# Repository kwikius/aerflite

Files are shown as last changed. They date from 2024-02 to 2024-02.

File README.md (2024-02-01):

A Fork of Ardupilot for a barebones STM32 running FreeRTOS and an onChip OSD
----------------------------------------------------------------------------

BuildInfo
---------

Building apm_quantracker

$$> export QUAN_TARGET_VEHICLE=QUAN_APM_ARDUPLANE

$$> export QUANTRACKER_ROOT_DIR=\<path to quantracker\>

$$> cd ardupilot/ArduPlane

$$> make quan

Dependencies
------------

The dependencies can be retrieved on linux by downloading building and running the installer
air_installer from github.  https://github.com/kwikius/air_installer

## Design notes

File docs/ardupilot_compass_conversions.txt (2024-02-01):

represnt z,y,z 1 means axis not flipped -1 means sign of axis flipped

output orientation  when chip is mounted on upper face of pcb and x is facing west

abbreviations W == wste,  E == east, S == south, N == north U = Up D = down
from datasheets where the chip text is written to be read normally x axis horizontal is pointing out to the right
e.g WNU is x points west , y points north, z points up
RHR is right hand rule

AK8963   [1,1,1]     ENU  or WSD  dependendt on part ( both RHR)        
AK09916  [1,1,1]     ENU
BMM150   [1,1,1]
HMC5843  [-1,1,-1]
IST8308  [1,1,-1]
IST8310  [1,1,-1]
LIS3MDL  [1,1,1]
LSM9DS1  [1,1,1]
LSM303   [1,1,1]
MAG3110  [1,1,1]
MMX5xx3  [1,1,1]
MMC3146  [1,1,1]
MSP      [1,1,1]
PX4      [1,1,1]
QMC5883  [-1,1,-1]
QURT     [1,1,-1]
RM3100    hardware modifiable?
Qflight [1,1,-1]

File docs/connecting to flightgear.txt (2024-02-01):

in (ardupilot) AP_HAL_SITL/SITL_State.cpp 99 connect to socket out from ardupilot to flightgear

in (ardupilot) AP_HAL_SITL/SITL_State.cpp 302 output to flightgear function

called from SITL_STATE::fdm_input_step through _fdm_input_local();

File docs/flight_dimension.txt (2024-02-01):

dimensions relating to flight
dimensions are within universe of a frame for example body_frame world_frame

angular_frame
 The pose within some linear_frame
   can be euler or quaternion 
   euler {pitch yaw roll}
   quaternion { w, x, y, z }

   pose : quaternion  
   angular_velocity : 3d vector angle/time
   angular_acceleration  3d vector angle / (time^2)
   Torque : 3d vector force * distance

linear_frame 
   position
   velocity
   acceleration
   jerk

aircraft related
   Thrust : linear_frame
   Drag : linear frame

FlightGear FlightDimension
   
   Thrust

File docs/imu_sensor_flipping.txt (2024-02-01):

IMU sensor flipping

The imu necessarily requires the sensor data to be in correct orientation

for aerflite the accel and gyro flipping is in the imu interrupt handler
in AP_HAL_QUAN/imu_task_aerflite.cpp
The compass flipping is in the Quan::compass_calculat function in AP_HAL_QUAN/lis3_mdl.cpp

AP inertial sensor parameters ............
Product id
Gyro Offsets
Accelerometer scaling
Accelerometer offsets
Gyro Filter
Accelerometer Filter
Use accelerometer
Still threshold
Gyro calibration scheme

AHRS parameters

GPS gain

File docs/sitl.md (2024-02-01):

Software in the loop
--------------------

SITL components
   - Physics
      - engine
      - actor specification
      - environment specification

  - Visualisation
      - engine
      - actor specification
      - environment specification

   - Sensors
      - Actor Pose
         - Linear position
         - Linear velocity
         - Linear acceleration
         - Angular position
         - Angular velocity
       - environment
         - wind

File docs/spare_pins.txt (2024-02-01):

Aerflite possible spare pins

PA4  currently used for video DAC out

PA12 CAN_TX
PA11 CAN_RX

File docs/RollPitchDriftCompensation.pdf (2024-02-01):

Roll-pitch compensation | - 1 - | December 1, 2011

Roll-Pitch Gyro Drift Compensation

William Premerlani, December 1, 2011

Problem
We wish to use an accelerometer and GPS to detect gyro roll-pitch drift in an IMU, without any information about orientation of the aircraft with respect to air speed vector.

Background
During the development of the theoretical foundations of MatrixPilot, the conventional wisdom of the DIY UAV community was that the best way to account for acceleration in roll-pitch drift compensation is to compute the acceleration in the body frame, using GPS acceleration to determine forward acceleration, and the cross product of the aircraft velocity vector with gyro rotation to compute cross acceleration. In order for this technique to be accurate, the angles of attack and side slip must be known, estimated, or assumed. In the case of fixed wing aircraft, this introduces errors during high acceleration. In the case multicopters, this introduces very large errors, because a multicopter does not naturally align itself with the direction of flight. So, a method that does not require attack and side slip angles would be more accurate.

Solution
The solution is trivial if you use gravity minus acceleration as the reference vector, rather than gravity. In the body (aircraft) frame of reference, the vectors reported by the accelerometer are the differences between the gravity and acceleration vectors, as seen in the body frame of reference:
( ) ( ) ( )
( )
( )
( ) output of accelerometer acceleration, asseen in body frame gravity, asseen in body frame

=

=

=

= -

t

t

t

t | t | t

b

b

b

b | b | b

A

a

g

A | g | a

Equation 1

Our estimate of the rotation matrix provides a connection between body and earth frame of reference:
( ) ( ) ( )

( )
( ) our estimate of the rotation matrix acceleration, asseen in earth frame gravity, asseen in earth frame

=

=

=

- = -

t

t

t | t | t

R

a

g

R | A | g a

e

e

b | e | e
Equation 2

If our estimate of the rotation matrix were correct, equation 2 would be an identity. However, because of gyro drift, equation 2 will not be exactly satisfied. In particular, the

Roll-pitch compensation | - 2 - | December 1, 2011

cross product of the vectors on the left and right hand side of Equation 2 is an indication of the drift error. To improve accuracy, it is a good idea to integrate both sides of the equation between GPS reports. That way we can use velocity information instead of acceleration:
( ) ( ) | ( 2 1) | ( ( 2) ( 1))

2

1

d | t | t | t | t

t

t

R | Ab | ge - Ve | - Ve · | · = | - · Ú t | t t | Equation 3

Use equation 3 on a regular basis (such as synchronized with GPS messages) to estimate drift. The left side is computed as the sum of multiplications of the rotation matrix with the accelerometer output. The first term on the right hand side is the time interval times the known, constant gravity vector. The second term is the difference in velocity vectors reported by the GPS.
Take the cross product of the left hand side of equation 3 with the right hand side. This is an indication of the drift rotation. Note that this method is capable of detecting yaw drift as well as roll-pitch, if the aircraft is accelerating laterally. So, it can be integrated with magnetometer yaw drift compensation. Also note that no assumptions have been made about the orientation of the aircraft.
So, the error rotation vector is given by:
( ) | ( ) ( ) | (( 2 1) | ( ( 2) ( 1))) 2

2

1

t | d | t | t | t | t

t

t

earth | b | e | Ve | Ve error | R | A | ¥ | - ·g - | - ˜

˜
¯

ˆ
Á

Á
Ë
Ê = | · | · Ú t | t t

Equation 4
Finally, transform the error in the body frame of reference. It can then be used directly as an input to the drift PI feedback controller:
( 2) | ( 2) t | t body | earth error | R | error T = | · | Equation 5

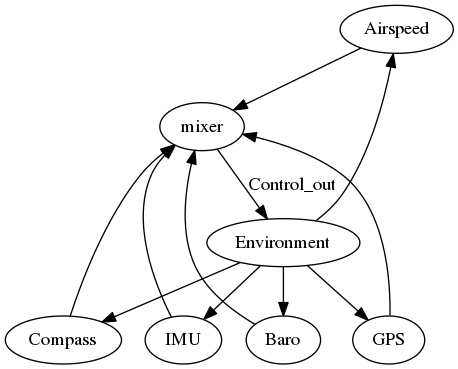
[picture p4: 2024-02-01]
docs/SITL/fc_as_mixer.png

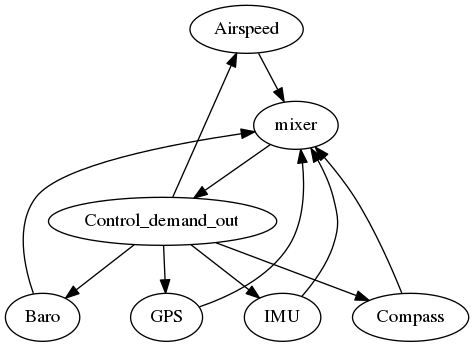
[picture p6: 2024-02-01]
docs/fc_mixer.png

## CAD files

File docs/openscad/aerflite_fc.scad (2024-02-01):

use <axes.scad>

module arrow_axes(){
   RHR_axes(){arrow();arrow(); arrow();}
}
module BMI160_arrow_n_rotation_axes(){
   RHR_axes(){
   arrow_n_rotation_arrow_rhs(); 
   arrow_n_rotation_arrow_rhs();
   arrow_n_rotation_arrow_rhs();
}
}

module board_arrow_n_rotation_axes(){
   rotate([180,0,0]){
   RHR_axes(){
   arrow_n_rotation_arrow_rhs(); 
   arrow_n_rotation_arrow_rhs();
   arrow_n_rotation_arrow_rhs();
}
}
}

translate([70,0,5]){
   translate([3,3,0]){
      text("board_orient",size = 2);
   }
   rotate([0,0,0]){
      board_arrow_n_rotation_axes();
   }
}


translate([0,50,5]){
   translate([3,3,0]){
      text("compass_orient",size = 2);
   }
   rotate([0,0,270]){
     arrow_axes();
   }
}


translate([-70,0,5]){
   translate([3,3,0]){
      text("BMI160_orient",size = 2);
   }
   rotate([0,0,90]){
      BMI160_arrow_n_rotation_axes();
   }
}

text_size = 2;
show_raspberry_pi = false;
module JST_SH1_horz(n_pins,name_text)
{
  translate([-4,-(n_pins + 2)/2,0]){
  	  cube ([4,n_pins + 2,3]);
  }
  translate([-2,-(n_pins + 3)/2,0]){
	  cube ([2,n_pins + 3,0.5]);
  }
  for ( i= [-(n_pins-1)/2:1: (n_pins-1)/2]){
	 translate([-5.5, i -0.25,0]){
		cube([1.5,0.5,0.25]);
	 }
  }
  translate([1,0,1]){
      text(name_text,size = text_size);
  }
}

module raspberry_pi_zero()
{
     difference(){
	 cube([65,30,5], center = true);
      translate([27,-1,-0]){
        rotate([0,180,0]){
        linear_extrude(height = 3) {
           text("Raspberry Pi Zero", size =  5);
        }
     }
      }
  }
}

module JST_GH_horz( n_pins,name_text)
{
  for ( i= [-(n_pins-1)/2:1: (n_pins-1)/2]){
	 translate([-5.4, i *1.25 -0.3,0]){
		cube([1.4,0.6,0.1]);
	 }
  }
  for ( i = [-1:2:1]){
		translate([-2.7,((n_pins-1)/2*1.25 +1.85)*i -0.5,0]){
			cube([2.7,1,0.1]);
		}
  }
  width = (n_pins-1) + 4.5;
  thickness = 0.5;
  difference(){
  translate([-4.05,-width/2,0]){
	cube([4.05,width,4.25]);
  }

  translate([-4.05 + thickness,-(width/2)+thickness,thickness]){
	cube([5,width - 2*thickness,4.25 - 2*thickness]);
  }
  }
   translate([1,0,1]){
      text(name_text,size = text_size);
  }
  
}

module JST_GH_vert( n_pins,name_text)
{
  for ( i= [-(n_pins-1)/2:1: (n_pins-1)/2]){
	 translate([-5.6, i *1.25 -0.3,0]){
		cube([1.7,0.6,0.1]);
	 }
  }
  for ( i = [-1:2:1]){
		translate([-2.8,((n_pins-1)/2*1.25 +1.85)*i -0.5,0]){
			cube([2.8,1,0.1]);
		}
  }
  width = (n_pins-1) + 4.5;
  thickness = 0.5;
  difference(){
  translate([-4.25,-width/2,0]){
	cube([4.25,width,4.05]);
  }

  translate([-4.25 + thickness,-(width/2)+thickness,thickness]){
	cube([4.25 - 2 * thickness,width - 2*thickness,5]);
  }
  }
  translate([1,0,1]){
      text(name_text,size = text_size);
  }
  
}


module hdr_pin()
{
	translate([-3,-0.32, -0.32]){
		cube([11.5,0.64,0.64]);
	}
   translate([0,-1.27,-1.27]){
		cube([2.54,2.54,2.54]);
	}
}
module rc_in_hdr()
{
	for (col = [-2.5:1:2.5]){
		for (row = [-1:1:1]){
         translate([0,col * 2.54,row * 2.54 +1.27]){
				hdr_pin();
		   }
		}
	}
}
module sd_socket()
{
   x = 12;
   y = 11.45;
   z = 1.6;
   
   translate([-x,-y/2,0]){
		cube([x,y,z]);
	}
    
   translate([1,0,1]){
      text("uSD Card",size = text_size);
  }
}


pcb_size = [77,35,1.5];
hole_spacing = [58, 23];
hole_dia = 3;

module pcb()
{
   difference(){
		translate(-pcb_size/2){
	     cube(pcb_size);
		}
		for (x_iter = [-1:2:1]){
			for (y_iter = [-1:2:1]){
	         translate([x_iter*hole_spacing[0]/2,
						y_iter*hole_spacing[1]/2,-(pcb_size[2]+1)/2]){
	             cylinder(d = hole_dia, h = pcb_size[2]+1, $fn = 20);
				}
			}
		}
   }
}

module mcu()
{
   color([0.3,0.3,0.3]){
		translate([-5,-5,0]){
		     cube([10,10,1]);
	   }
   }
    color([0.7,0.7,0.7]){
   translate([-7,-7,0]){
       cube([14,14,0.2]);
	}
   }
}

module aerflite_fc() {
 // headers
  rotate([0,0,180]){
 	 translate([pcb_size[0]/2,0,0]){
			rc_in_hdr();
	  }
  }

  translate([-7,0,-pcb_size[2]/2]){
    rotate([0,180,0]){
      mcu();
    }
  }

  color([0.5,0.1,0.5]){
    pcb();
  }
if (show_raspberry_pi){
  translate([0,0,-5]){
     raspberry_pi_zero();
  }
}
  
  translate([pcb_size[0]/2 -1,0.5,pcb_size[2]/2]){
	 sd_socket();
  }
//-----------------
// rear side with RC out
   // stbd top
  //P1 CAN
  translate([-pcb_size[0]/2,-12,pcb_size[2]/2]){
   rotate([0,0,180]){
   JST_GH_vert(4,"CAN");
	}
  }
   // stbd bottom 
  //P2 CAN
   translate([-pcb_size[0]/2,-12,-pcb_size[2]/2]){
   rotate([180,0,180]){
   JST_GH_horz(4,"CAN");
	}
  }
  //P7  Usart3
  translate([-pcb_size[0]/2,12,pcb_size[2]/2]){
   rotate([0,0,180]){
   JST_GH_vert(4,"UART3(GPS)");
	}
  }
  //P8 Usart4
  translate([-pcb_size[0]/2,12,-pcb_size[2]/2]){
   rotate([180,0,180]){
   JST_GH_horz(4,"UART_(unused)");
	}
  }
//----------------------------------
//  front side with uSD_Card
  //top left
  //P4 power horz
  translate([pcb_size[0]/2,12.5,pcb_size[2]/2]){
   JST_GH_horz(2,"VIN 8V~16V");
  }
//bottom left
  //P5 power horz
  translate([pcb_size[0]/2,12.5,-pcb_size[2]/2]){
   rotate([180,0,0]){
   JST_GH_horz(2,"VIN 8V~16V");
	}
  }
//top right
 //P3 video out
  translate([pcb_size[0]/2,-11.75,pcb_size[2]/2]){
   JST_GH_horz(4,"VIDEO OUT");
  }
//bottom right
  // P22 camera Video in
   translate([pcb_size[0]/2,-12.5,-pcb_size[2]/2]){
   rotate([180,0,0]){
   JST_GH_horz(3,"VIDEO IN");
	}
  }
//------------------------------
// port side front to back
// P19 5V out
  translate([22.5,pcb_size[1]/2,pcb_size[2]/2]){
	 rotate([0,0,90]){
    	JST_GH_vert(3,"5V OUT 1A");
	 }
  }

  //P20 analog_in
  translate([13,pcb_size[1]/2,pcb_size[2]/2]){
	 rotate([0,0,90]){
    	JST_GH_vert(3,"ANALOG IN");
	 }
  }

  // prog
  translate([-4,pcb_size[1]/2,pcb_size[2]/2]){
	 rotate([0,0,90]){
    	JST_SH1_horz(2,"PROG");
	 }
  }
   // jtag
  translate([4,pcb_size[1]/2,pcb_size[2]/2]){
	 rotate([0,0,90]){
    	JST_SH1_horz(4,"JTAG");
	 }
  }

  //P23 Batt current
  translate([-12,pcb_size[1]/2,pcb_size[2]/2]){
	 rotate([0,0,90]){
    	JST_GH_vert(3,"BATTI");
	 }
  }
 //P9 usart6
 translate([-21,pcb_size[1]/2,pcb_size[2]/2]){
	 rotate([0,0,90]){
    	JST_GH_vert(4,"UART6(tracker)");
	 }
  }

//----------------------
//stbd side front to back
//P24 Aux video in
   translate([22,-pcb_size[1]/2,pcb_size[2]/2]){
	 rotate([0,0,-90]){
    	JST_GH_vert(3,"AUX VIDEO IN");
	 }
  }
  //P11 RC In
  translate([12,-pcb_size[1]/2,pcb_size[2]/2]){
	 rotate([0,0,-90]){
    	JST_GH_vert(5,"RC IN");
	 }
  }

   //P21 Airspeed
   translate([0.5,-pcb_size[1]/2,pcb_size[2]/2]){
	 rotate([0,0,-90]){
    	JST_GH_vert(3,"AIRSPEED IN");
	 }
  }

  //P6 I2C
  translate([-10.5,-pcb_size[1]/2,pcb_size[2]/2]){
	 rotate([0,0,-90]){
    	JST_GH_vert(5,"I2C");
	 }
  }

  //P10 usart6
   translate([-21,-pcb_size[1]/2,pcb_size[2]/2]){
	 rotate([0,0,-90]){
    	JST_GH_vert(4,"UART1(console)");
	 }
  }
  
  translate ([100,0,20]){
     // text ("Hello world");
  }
}

aerflite_fc();

  

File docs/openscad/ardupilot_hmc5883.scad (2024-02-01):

use <axes.scad>



module arrow_axes(){
   RHR_axes(){arrow();arrow(); arrow();}
}

module ic(){
   translate([-10,-10,0]){
    
   cube([20,20,5]);

       
   translate([4,4,5]){
       color("black"){
      sphere( d = 3);
   }
         }
}
}


ic();
translate([0,0,25]){
rotate([0,180,0]){
arrow_axes();
}
}
translate([-10,15]){
text(" Ardupilot HMC5883");
}

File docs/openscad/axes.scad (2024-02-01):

module arrow(){
   body_h = 10;
   d = 1;
   arrow_base = 2;
   arrow_head_length = 4;
   
   translate([0,0,body_h]){
   cylinder ( d1 = arrow_base, d2 = 0.01, h =arrow_head_length, $fn = 20);
   }
   cylinder( d= 1, h = body_h,$fn = 20);
}

module rotation_arrow_rhs(){
rotate_extrude(angle = 120){
   translate([4,0,0]){
      circle ( d= 1, $fn = 20);
   }
}
rotate([0,0,120]){ 

rotate([90,0,0]){
      translate([4,0,-2]){
      cylinder ( d1 = 0.01, d2 = 1.75, h =2.5, $fn = 20);
   }
}
}
}
module rotation_arrow_lhs(){
   mirror([0,1,0]){
      rotation_arrow_rhs();
   }
}




module arrow_n_rotation_arrow_rhs(){
   arrow();
translate([0,0,9]){
rotation_arrow_rhs();
}
}

module arrow_n_rotation_arrow_lhs(){
   arrow();
translate([0,0,9]){
rotation_arrow_lhs();
}
}

//arrow();
module RHR_axes(){
   color("red"){
      translate([15,-2,-2]){
         rotate([0,-90,0]){
            text("X", size = 4);
         }
      }
      rotate([0,90,0]){
         children(0);
      }
   }  
   color("green"){
      translate([-2,15,-2]){
         rotate([90,0,0]){
            text("Y", size = 4);
         }
      }
      rotate([-90,0,0]){
       children(1);
      }
   }   
   
   color("blue"){
   translate([-2,-2,15]){
       rotate([0,0,0]){
          text("Z", size = 4);
       }
   }
   rotate([0,0,0]){
      children(2);
      }
   }   
   
}


RHR_axes(){
   arrow_n_rotation_arrow_rhs(); 
   arrow_n_rotation_arrow_rhs();
   arrow_n_rotation_arrow_rhs();
}




//RHR_axes();

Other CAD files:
docs/openscad/hmc5883.scad
Tools/autotest/aircraft/arducopter/Models/Untitled.skp
Tools/autotest/aircraft/arducopter/Models/Y6_test.skp
Tools/autotest/aircraft/arducopter/Models/Y6_test2.skp
Tools/autotest/aircraft/arducopter/Models/_propeller0_.skp
Tools/autotest/aircraft/arducopter/Models/plus_quad.skp
Tools/autotest/aircraft/arducopter/Models/plus_quad2.skp
Tools/autotest/aircraft/arducopter/Models/quad.skp
Tools/autotest/aircraft/easystar/Models/easystar.blend
docs/openscad/NED_axes.scad

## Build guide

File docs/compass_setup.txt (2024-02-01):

Compass setup
11:51 May 07 2017
The compass setup is currently not optimal.

If you change compass orientation, then you need to manually rotate the compass offsets to follow.

Ideally the offsets would be in the compas plane then this wouldnt be necessary

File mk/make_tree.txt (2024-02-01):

apm.mk
   environ.mk
      ## opt to config.mk and developer.mk
     // defines board
   targets.mk
      ## does nothing mostly

   sketch_sources.mk
      $(SRCROOT)/make.inc

   board_$BOARD_NAME.mk

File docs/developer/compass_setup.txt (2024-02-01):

Compass setup
11:51 May 07 2017
The compass setup is currently not optimal.

If you change compass orientation, then you need to manually rotate the compass offsets to follow.

Ideally the offsets would be in the compass plane then this wouldnt be necessary

Final Compass orientation should be relative to the heading of the vehicle.

simple case
Final Compass is orientated so that if  aircraft is pointing north
x is max y is 0, e,g North is in direction of x axis

TODO try reversing z in compass z should be +ve when straight n level as positive z is down.
See comments in COMPASS_ORIENT parameter in Compass.cpp

Try setting COMPASS_ORIENT param to NONE
look at why

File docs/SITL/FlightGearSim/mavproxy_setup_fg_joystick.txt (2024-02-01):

N.B only currently works on my fork of main ardupilot on "sitl-joystick" branch
Get FlightGear sim working with mavproxy sitl.

to build
Customised version of ardupilot to connect a joystick to sitl direct

checkout the branch "sitl-joystick"
N.B from current master, also need to update modules. 
Do git submodule init , git submodule update --recursive
in ardupilot dir do 
make sitl plane or 
but may need to messa bout with mavlink calss which have chaged
./waf configure --board sitl
./waf plane

Could use make but would need to add path to quan to includes.
This has been done for sitl in 

   ardupilot/Tools/ardupilotwaf/boards.py

   (see around line 200)

Switch on Taranis. Make sure the model MvPrxyJSBSim is selected
 then Plug in Taranis to usb port on PC

Open a terminal
cd /ardupilot/Tools/autotest

Since the joystick is connected to sitl direct
in fg_plan_view.sh add the option, 

 --prop:/input/joysticks/js[0]=0 \
which stops Flighgear using the joystick for input

 run fg_plane_view.sh

wait for FlightGear to settle down

Open another terminal

cd to ardupilot/ArduPlane

put jsbsim executable mavproxy and autotest in your path e.g using export
(I already installed mavproxy using pip install mavproxy)
do setup_sim.sh
or
e.g
export PATH=$PATH:$HOME/cpp/projects/jsbsim/src
export PATH=$PATH:$HOME/cpp/projects/ardupilot/Tools/autotest
export PATH=/usr/lib/ccache:$PATH

run sim_vehicle.py -j4 -L KSFO

when console starts do 

 arm throttle

Taranis settings
(Raw values of number are +- 32767 for raw joystick or +- 1 for mixer_lang)

Throttle : low throttle is negative  , high throttle is positive

Rudder :To Go left is positive of zero, to go right is negative

Pitch : Pitch down is positive, pitch up is negative

Aileron : from pilots view Roll clockwise rel earth is positive, roll anti-clockwise is negative

channel 8 is Flight control
// params in plane.parm and plane-jsbsim.parm
FLTMODE1        10
FLTMODE2        11
FLTMODE3        12
FLTMODE4        5
FLTMODE5        2
FLTMODE6        0
FLTMODE_CH      8

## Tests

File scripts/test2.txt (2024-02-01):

ls
/:
 dev/
 etc/
 fs/
nsh> [K
nsh> [K/:
nsh: /:: command not found
nsh> [K
nsh> [K dev/
nsh: dev/: command not found
nsh> [K
nsh> [K etc/
nsh: etc/: command not found
nsh> [K
nsh> [K fs/
nsh: fs/: command not found
nsh> [K
nsh> [Knsh> sh /etc/init.d/rc.APM
nsh: nsh>: command not found
nsh> [K
nsh> [KMounting binfs 
nsh: Mounting: command not found
nsh> [K
nsh> [Kbinfs mounted OK 
nsh: binfs: command not found
nsh> [K
nsh> [Knsh: rm: unlink failed: No such file or directory
nsh: nsh:: command not found
nsh> [K
nsh> [KDetected FMUv2 board 
nsh: Detected: command not found
nsh> [K
nsh> [Kuorb started OK 
INFO  Usage: uorb 'start', 'test', 'latency_test' or 'status'
nsh> [K
nsh> [KTrying PX4IO board 
nsh: Trying: command not found
nsh> [K
nsh> [KPX4: param_find(SYS_RESTART_TYPE)
nsh: PX4:: command not found
nsh> [K
nsh> [KPX4: param_find(CBRK_IO_SAFETY)
nsh: PX4:: command not found
nsh> [K
nsh> [K[px4io] default PWM output device
nsh: [px4io]: command not found
nsh> [K
nsh> [KPX4: param_find(CBRK_FLIGHTTERM)
nsh: PX4:: command not found
nsh> [K
nsh> [KPX4IO board OK 
nsh: PX4IO: command not found
nsh> [K
nsh> [KPX4: param_find(RC_DSM_BIND)
nsh: PX4:: command not found
nsh> [K
nsh> [KPX4: param_find(BAT_V_SCALE_IO)
nsh: PX4:: command not found
nsh> [K
nsh> [KPX4: param_find(RC_FAILS_THR)
nsh: PX4:: command not found
nsh> [K
nsh> [KPX4: param_find(RC_FAILS_THR)
nsh: PX4:: command not found
nsh> [K
nsh> [KPX4: param_find(CBRK_FLIGHTTERM)
nsh: PX4:: command not found
nsh> [K
nsh> [KPX4: param_find(RC_RSSI_PWM_CHAN)
nsh: PX4:: command not found
nsh> [K
nsh> [KPX4: param_find(RC_RSSI_PWM_MAX)
nsh: PX4:: command not found
nsh> [K
nsh> [KPX4: param_finPWPh
nsh: PX4:: command not found
nsh> [K
nsh> [KPX0) m 2 (8ce 
nsh: PX0): command not found
nsh> [KmKgd3d stameas_aer stt faicted t0dge  senson Ibus/M0  /detialisinisha0\00\00\0ng APM00\00ng b00\00Q
nsh: mKgd3d: command not found
nsh> [Kdisa\FD0\000\0-
nsh: disa\FD0\000\0-: command not found
nsh> [KA_\00\\0

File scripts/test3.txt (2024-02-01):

sh /etc/init.d/rc.APM
Mounting binfs 
binfs mounted OK 
nsh: rm: unlink failed: No such file or directory
Detected FMUv2 board 
uorb started OK 
Trying PX4IO board 
PX4: param_find(SYS_RESTART_TYPE)
PX4: param_find(RC_RSSI_PWM_CHAN)
PX4: param_find(RC_RSSI_PWM_MAX)
PX4: param_find(RC_RSSI_PWM_MIN)
PX4: param_find(CBRK_IO_SAFETY)
px4io default PWM output device
PX4: param_find(CBRK_FLIGHTTERM)
PX4IO board OK 
PX4: param_find(RC_DSM_BIND)
PX4: param_find(BAT_V_SCALE_IO)
PX4: param_find(RC_FAILS_THR)
PX4: param_find(RC_FAILS_THR)
PX4: param_find(CBRK_FLIGHTTERM)
PX4: param_find(RC_RSSI_PWM_CHAN)
PX4: param_find(RC_RSSI_PWM_MAX)
PX4: param_find(RC_RSSI_PWM_MIN)
PX4: param_find(PWM_MAIN_REV1)
PX4: param_find(PWM_MAIN_REV2)
PX4: param_find(PWM_MAIN_REV3)
PX4: param_find(PWM_MAIN_REV4)
PX4: param_find(PWM_MAIN_REV5)
PX4: param_find(PWM_MAIN_REV6)
PX4: param_find(PWM_MAIN_REV7)
PX4: param_find(PWM_MAIN_REV8)
PX4: param_find(PWM_MAIN_REV9)
PX4: param_find(PWM_MAIN_REV10)
PX4: param_find(PWM_MAIN_REV11)
PX4: param_find(PWM_MAIN_REV12)
PX4: param_find(PWM_MAIN_REV13)
PX4: param_find(PWM_MAIN_REV14)
PX4: param_find(PWM_MAIN_REV15)
PX4: param_find(PWM_MAIN_REV16)
PX4: param_find(TRIM_ROLL)
PX4: param_find(TRIM_PITCH)
PX4: param_find(TRIM_YAW)
PX4: param_find(PWM_SBUS_MODE)
px4io: CRCs match
PX4IO CRC OK 
PX4: param_find(CBRK_IO_SAFETY)
Set FMU mode_pwm4 
started mtd driver OK 
reading /fs/mtd expecting 16384 bytes
readtest OK
mtd readtest OK 
rwtest /fs/mtd testing 16384 bytes
rwtest OK
mtd rwtest OK 
adc init done
adc started OK 
Starting ArduPilot /dev/ttyACM0 /dev/ttyS1 /dev/ttyS2 
Starting Scheduler_test uartA=/dev/ttyACM0 uartC=/dev/ttyS1 uartD=/dev/ttyS2 uartE=/dev/ttyS6
initialised /dev/ttyACM0 OK 4096 1024
initialised /dev/ttyS3 OK 1024 512
initialised /dev/ttyS1 OK 1024 512
initialised /dev/ttyS2 OK 1024 512
initialised /dev/ttyS6 OK 1024 512
ArduPilot started OK 
rc.APM finished 
nsh> [KNo INS backends available

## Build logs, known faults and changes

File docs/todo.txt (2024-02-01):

remove HIL_SUPPORT
try enabling airspeed to use in ahrs tecs calcs etc

watchdog thread. All threads report to watchdog thread. If a thread doesnt report then take action

internal video mode

Plane::smoothed_airspeed. Is this necessary?

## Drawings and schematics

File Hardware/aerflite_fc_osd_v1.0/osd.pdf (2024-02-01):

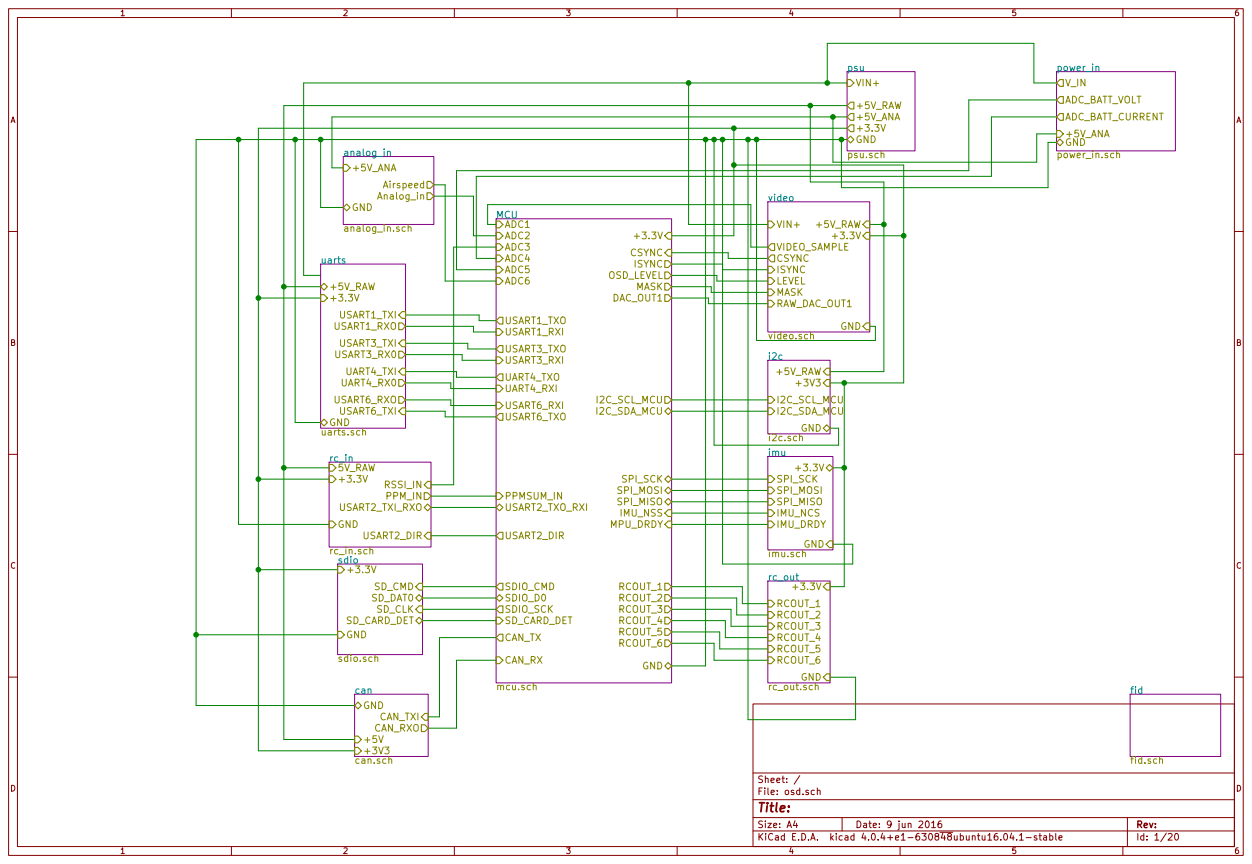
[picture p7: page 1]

psu
psu.sch VIN+ GND

5V_RAW +3.3V USART2_TXI_RXO GND USART2_DIR | RSSI_IN PPM_IN

SPI_SCK SPI_MISO | +3.3V GND

Id: 1/20 Title: File: osd.sch Sheet: / can
can.sch GND
CAN_TXI +3V3 +5V
CAN_RXO

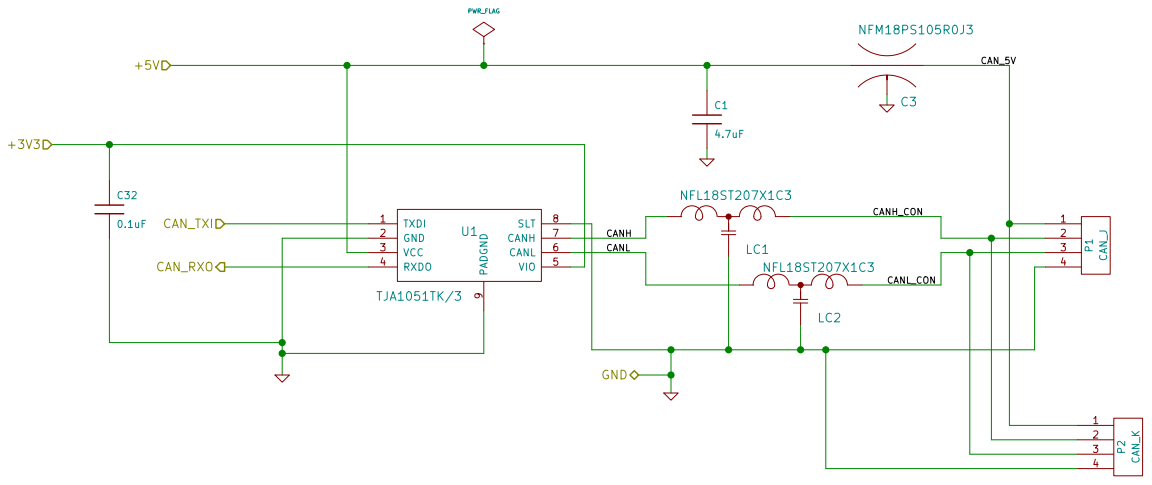
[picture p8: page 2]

Id: 2/20 Title: File: can.sch Sheet: /can/

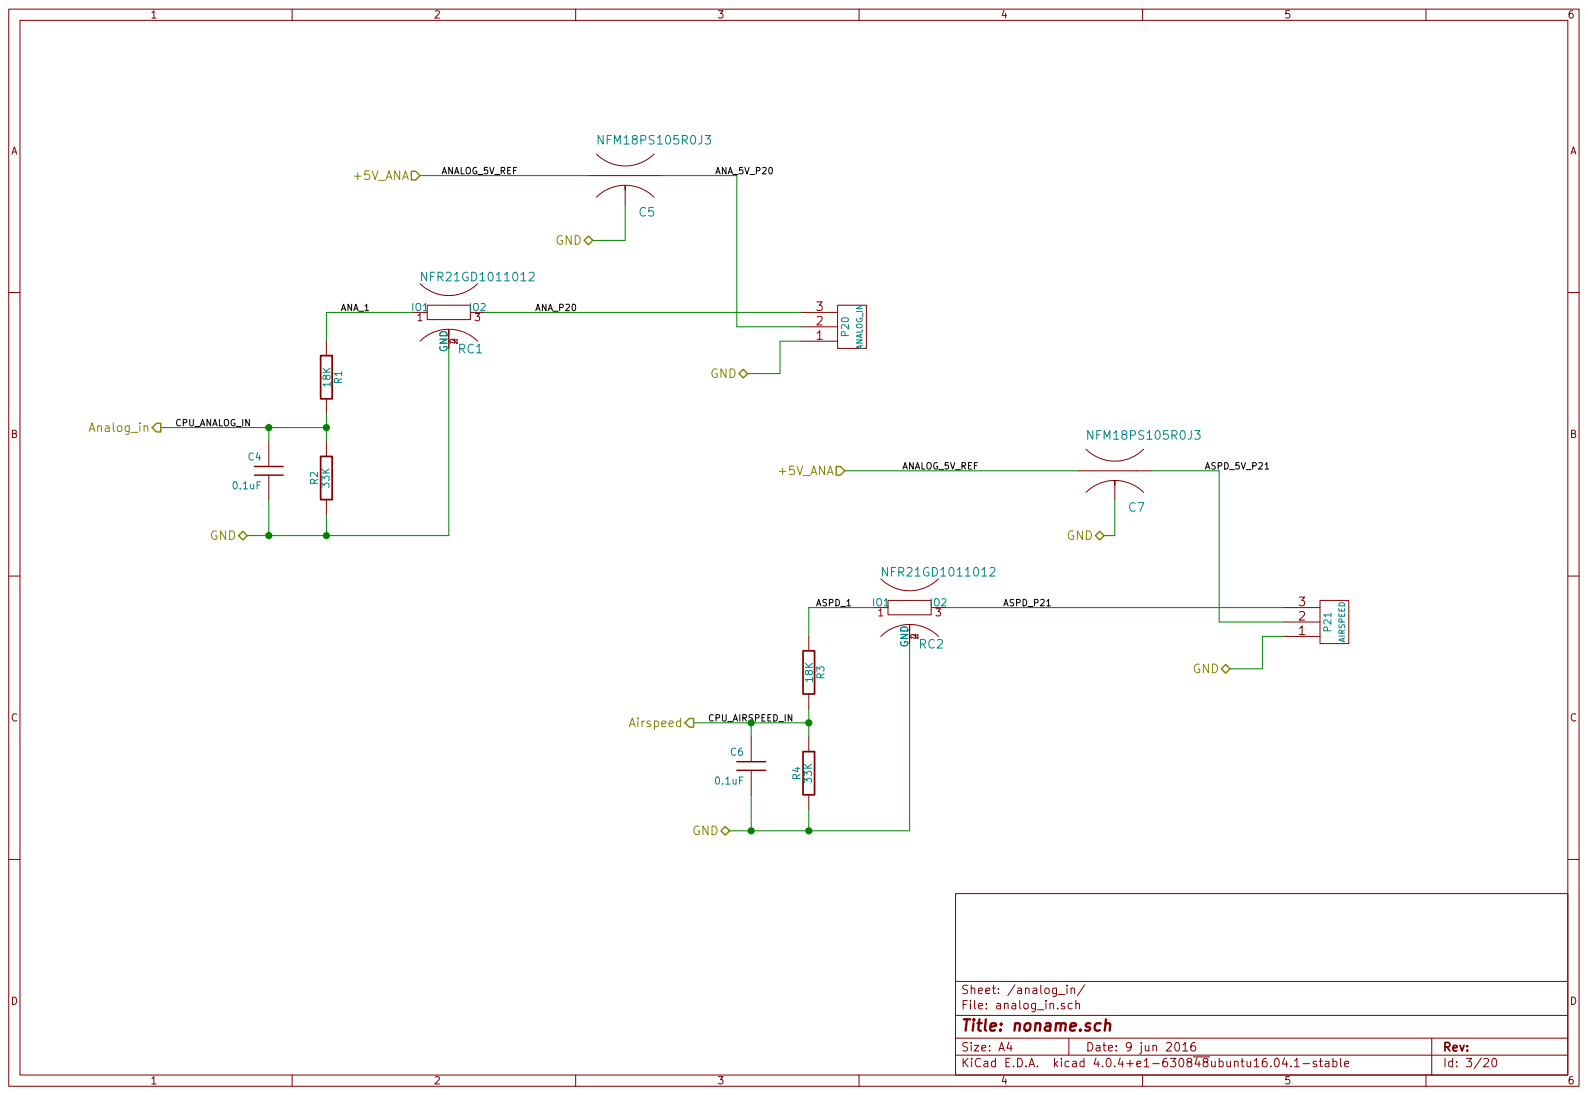
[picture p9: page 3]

File: analog_in.sch
Id: 3/20 Title: noname.sch

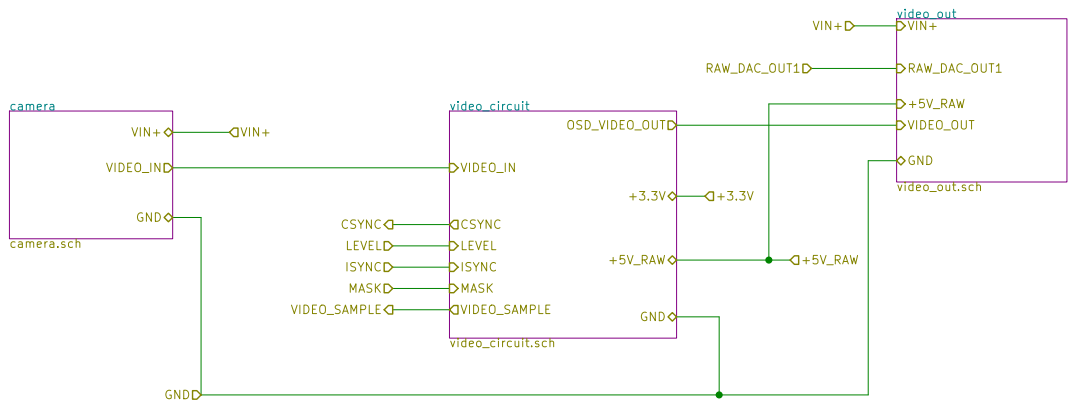
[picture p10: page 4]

Id: 4/20 Title: File: video.sch Sheet: /video/

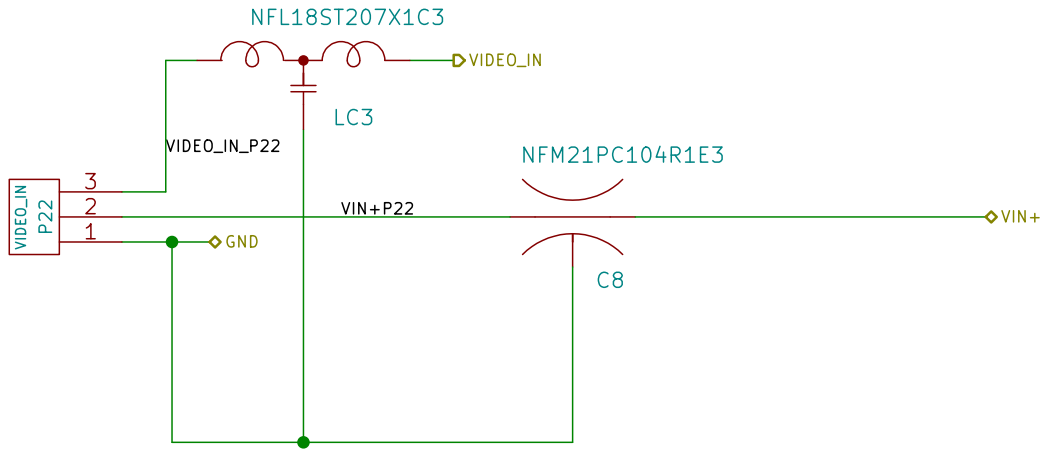
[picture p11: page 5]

Id: 5/20 Title: File: camera.sch Sheet: /video/camera/

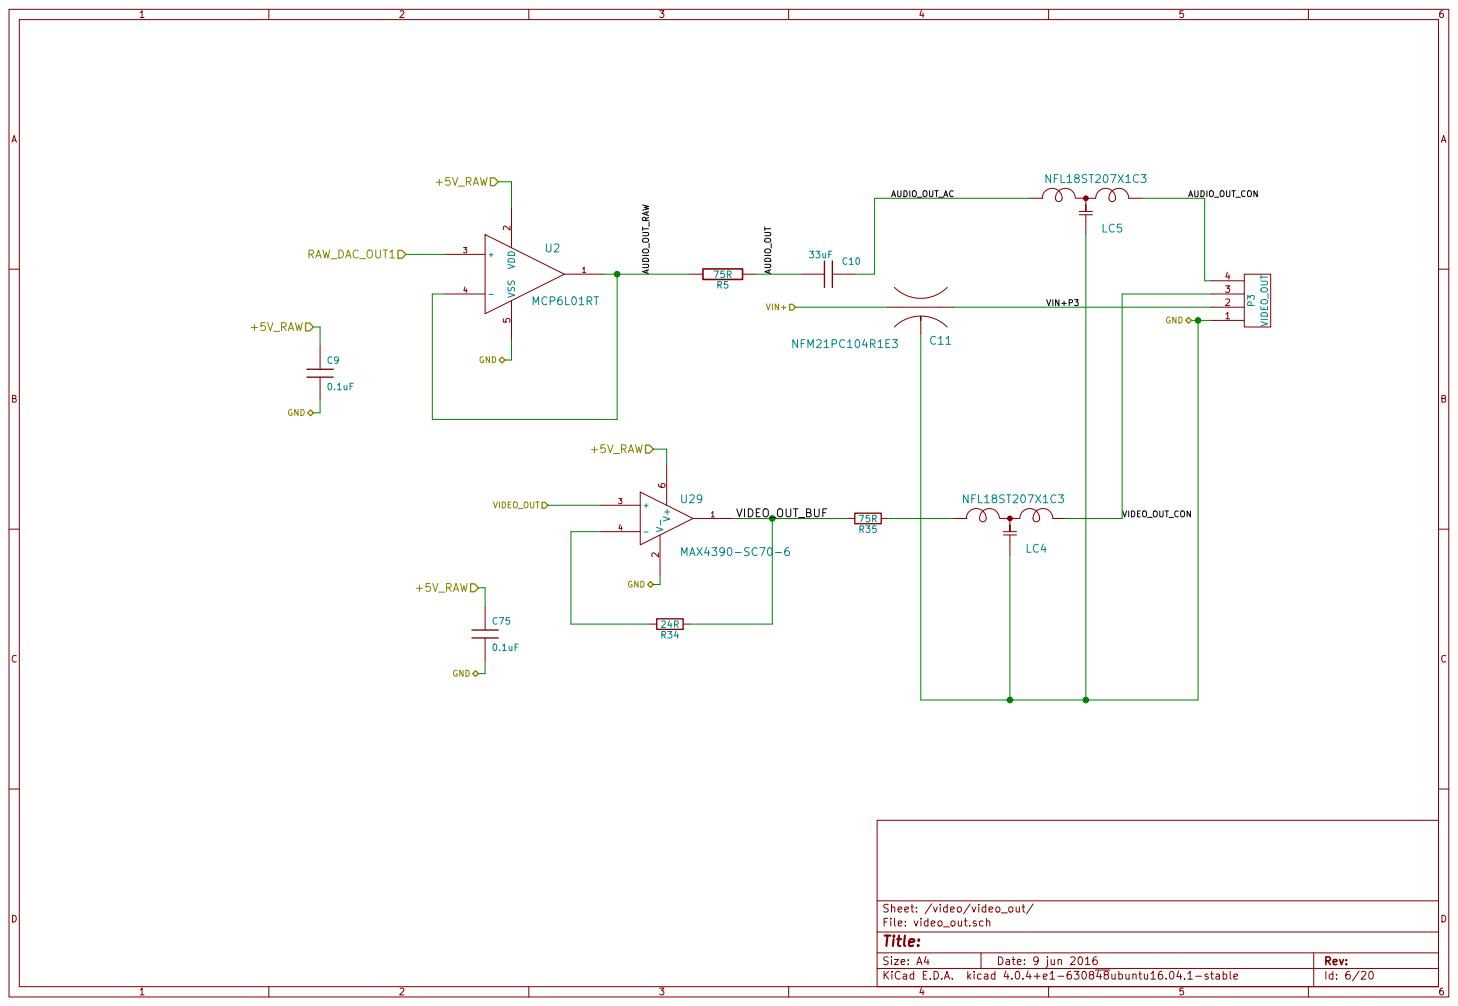
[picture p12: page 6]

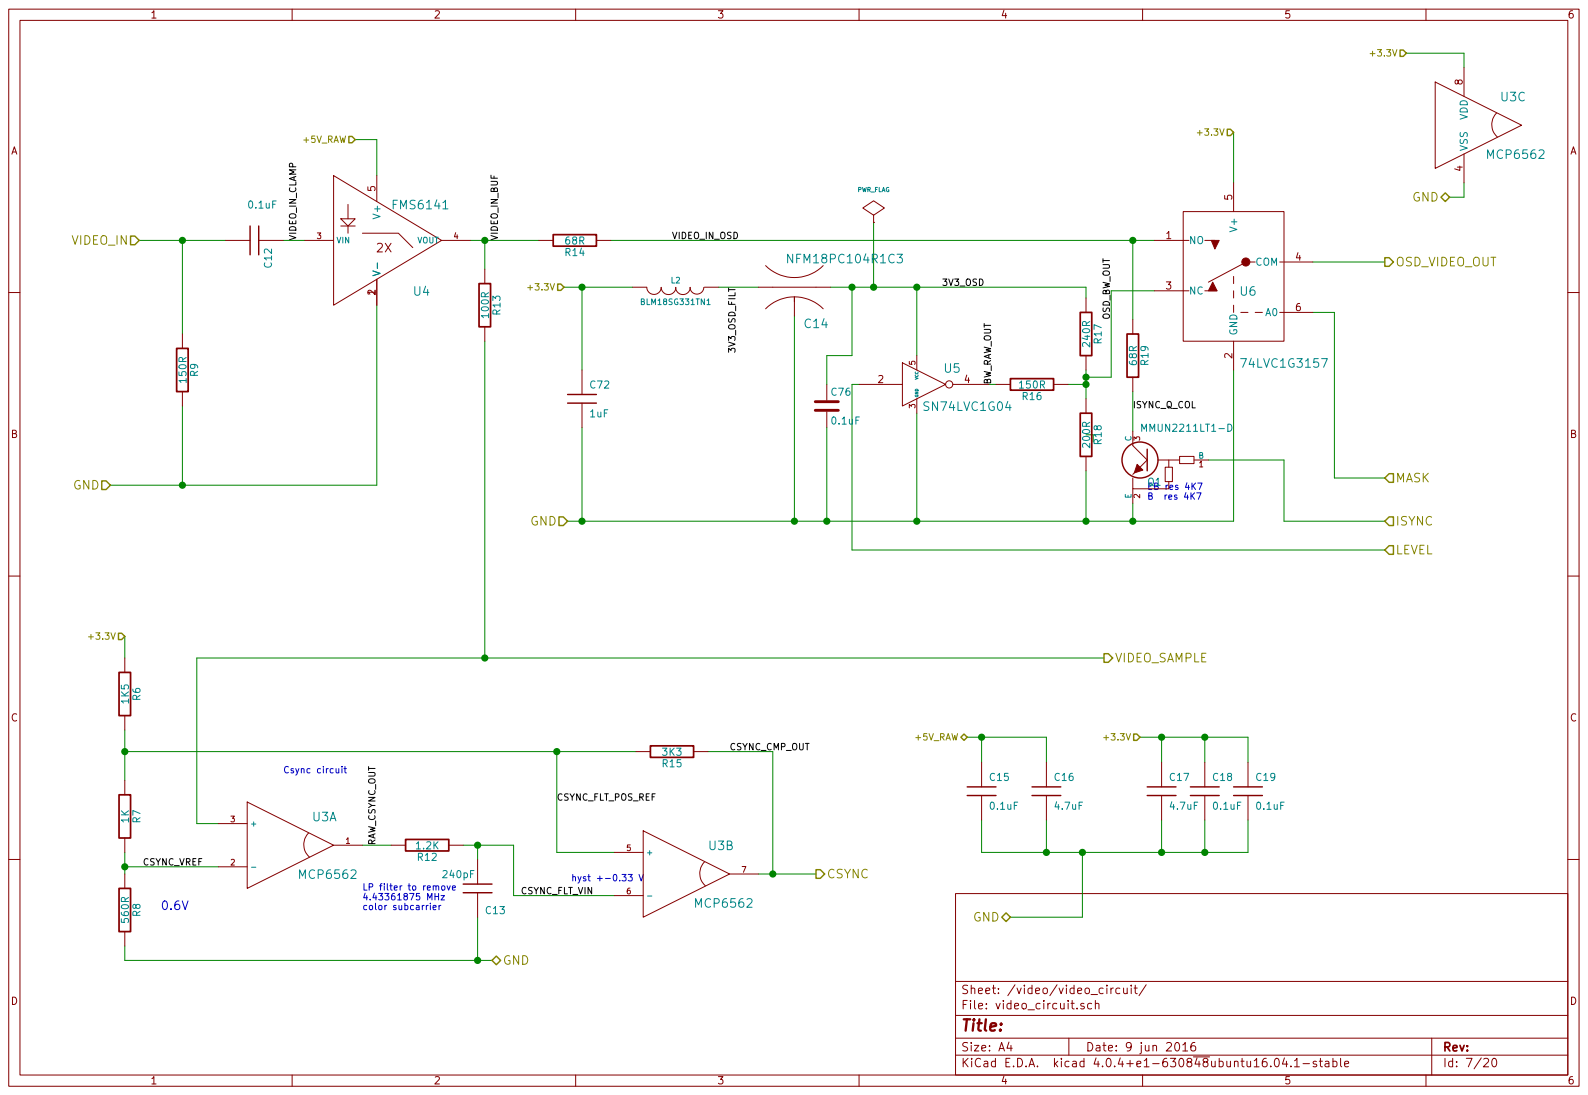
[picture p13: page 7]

LP filter to remove
4.43361875 MHz

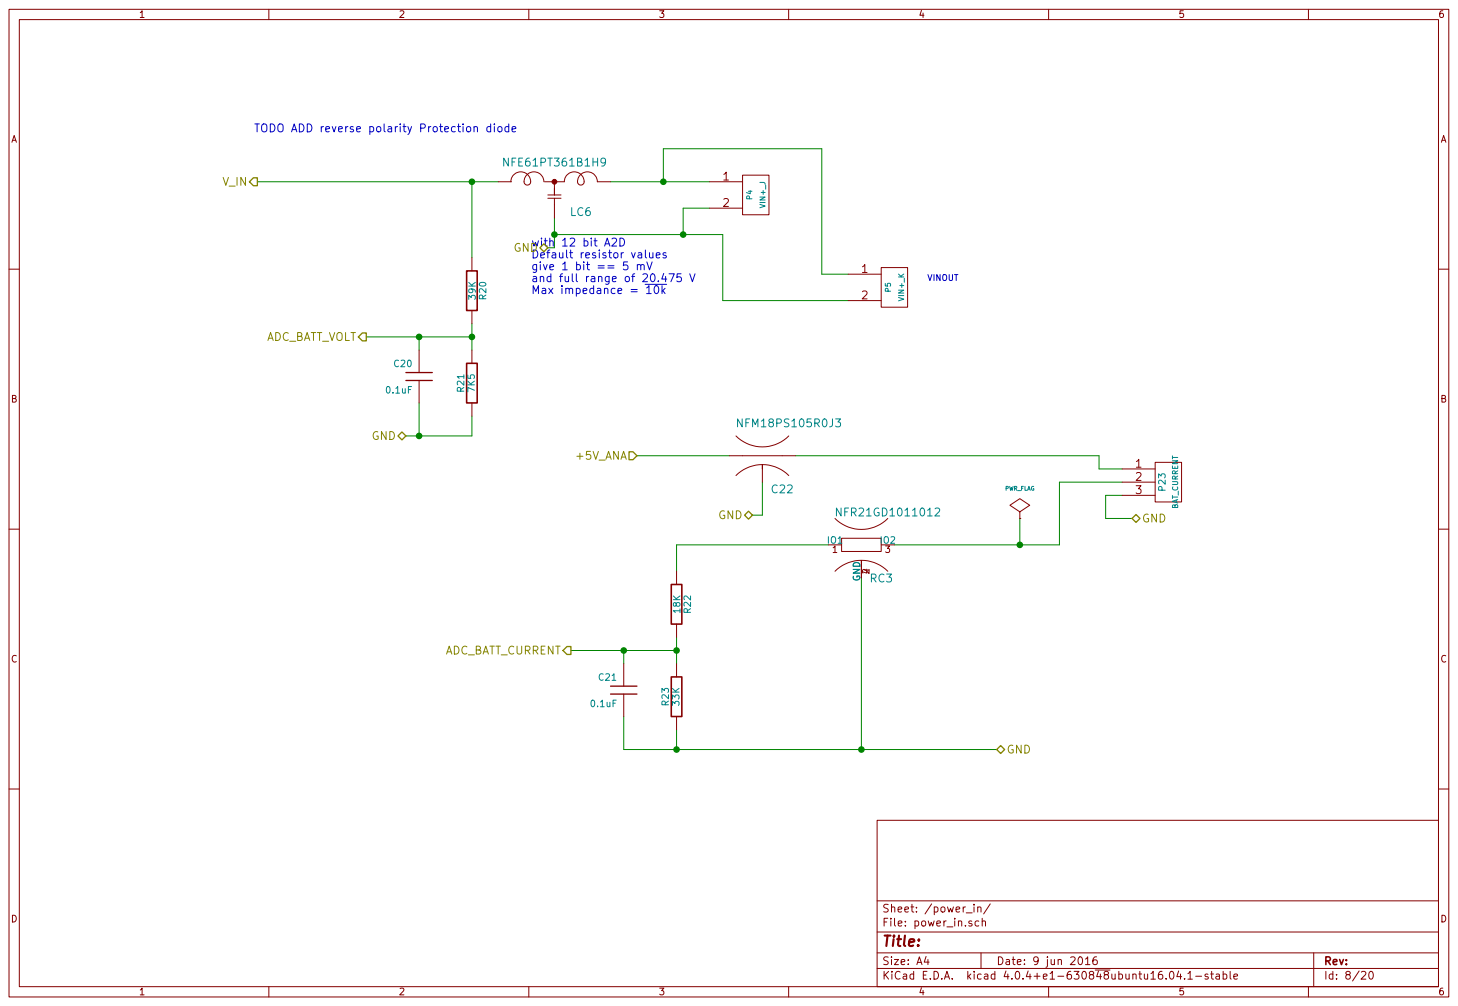
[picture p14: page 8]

TODO ADD reverse polarity Protection diode

NFM18PS105R0J3 with 12 bit A2D
GND
Default resistor values give 1 bit == 5 mV
and full range of 20.475 V
Max impedance = 10k

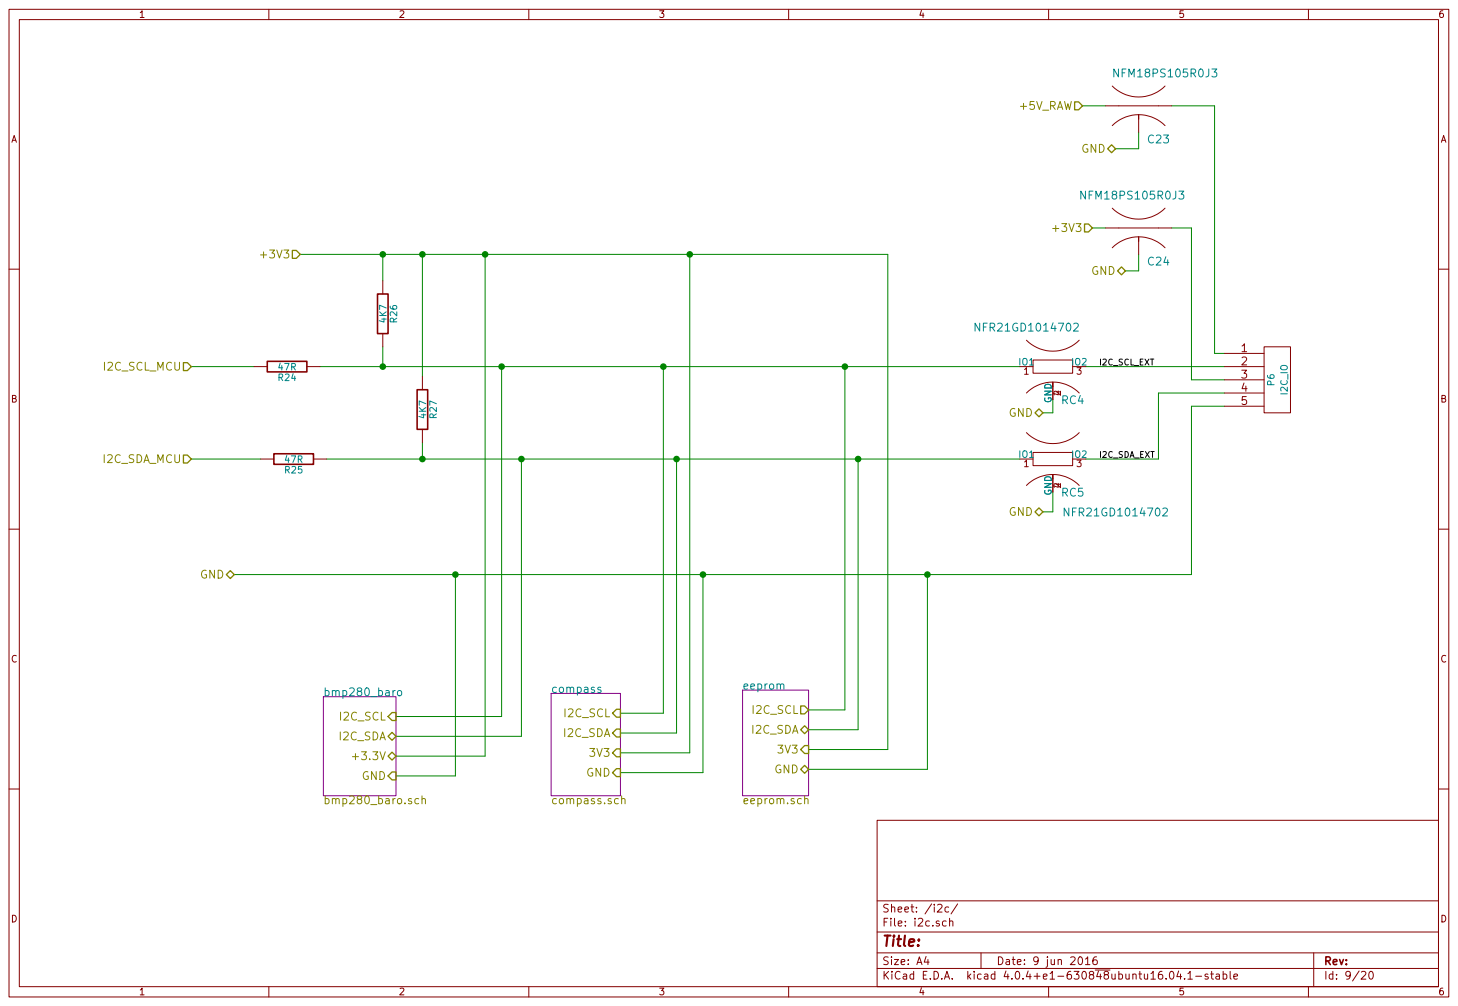
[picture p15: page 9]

Id: 9/20 Title: File: i2c.sch Sheet: /i2c/

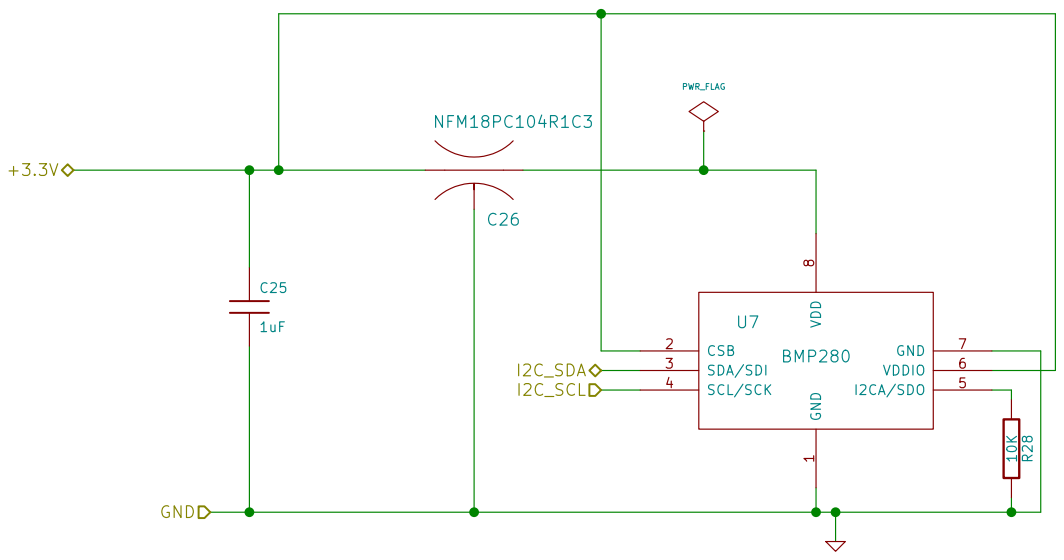
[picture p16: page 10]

1 CSB 2 SDA/SDI 3 SCL/SCK 4

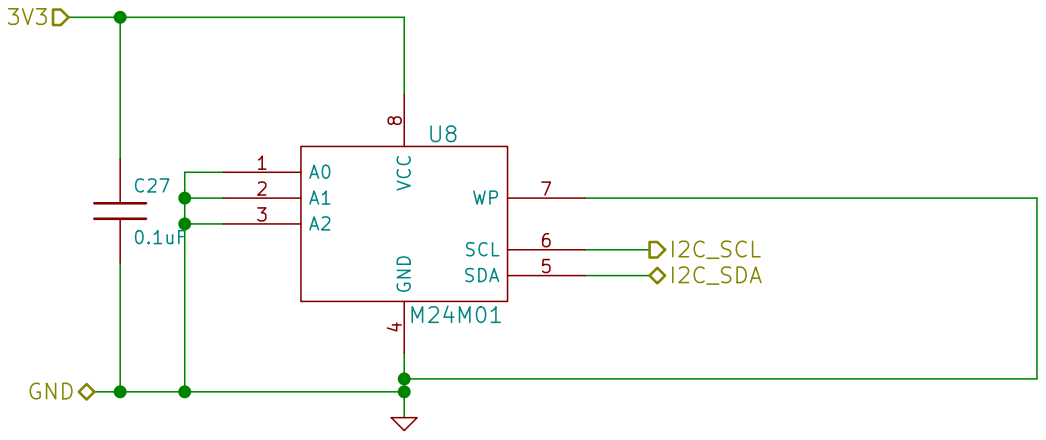
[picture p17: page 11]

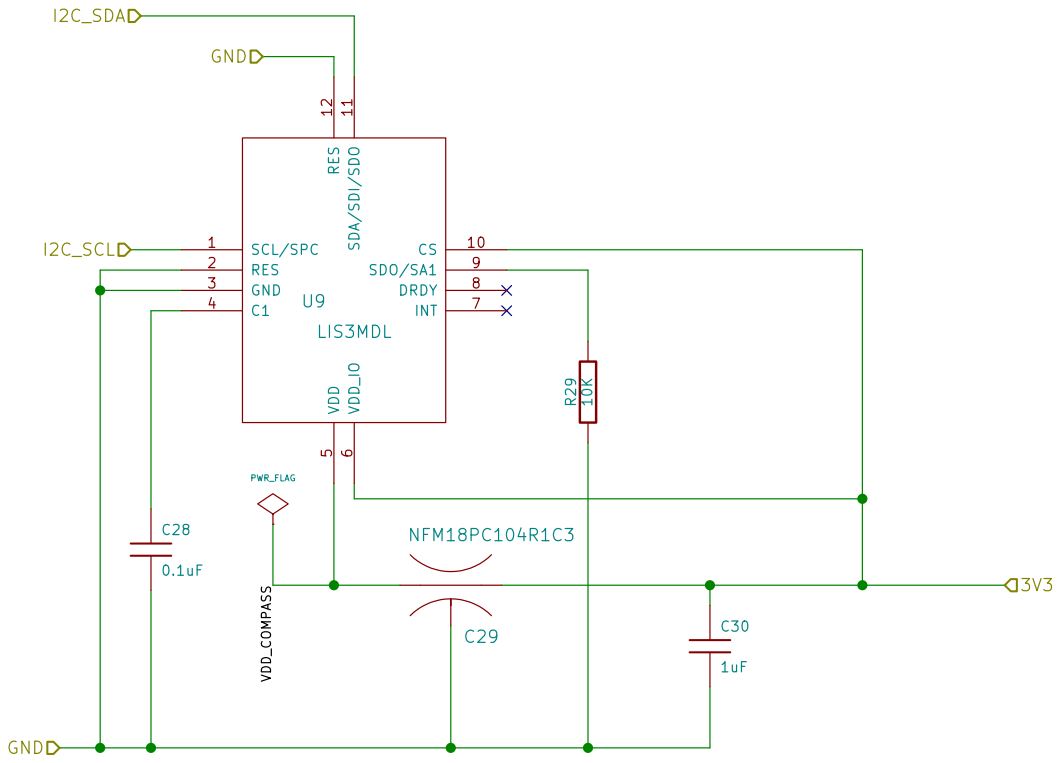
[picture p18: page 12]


Id: 13/20 Title: File: uarts.sch Sheet: /uarts/ UART4_RX1 UART4_TX1 USART3_RX1 USART3_TX1 USART3_SIGN


RC receiver connector
based on FrSKY D4-RII
with PPM_SUM, RSSI
and Telemetry

Component Values
For FrSky D4R-II
(R44 is a link,C43,R45 not fitted) C40



Id: 16/20 Title: File: imu.sch Sheet: /imu/C44


Id: 17/20 Title: File: fid.sch Sheet: /fid/


Amphenol SD card holder 101-00581-59 C46


Use resonator Murata CSTCE8M00GH5C99-R0 TODO

4 P15 JTAG SWCLK 3


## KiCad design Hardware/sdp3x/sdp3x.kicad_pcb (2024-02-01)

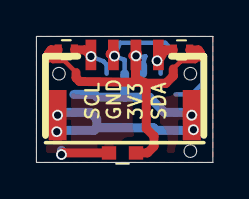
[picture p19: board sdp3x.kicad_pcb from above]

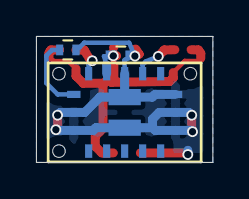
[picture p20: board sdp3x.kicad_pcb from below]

Board: 2 copper layers, 9.8 x 7.0 mm, 7 parts (3 on the bottom side), 5 nets.

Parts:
C1: C; C_0402
C2: C; C_0603
J1: Conn_01x04; JST_GH4_vert
R1, R2, R3: R; R_0402
U1: SDP3x_I2C; SDP3x_i2c

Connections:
/SCL: J1.1, R2.2, U1.5
/SDA: J1.4, R1.2, U1.8
/VDD: C1.1, C2.1, J1.3, R1.1, R2.1, U1.7
GND: C1.2, C2.2, J1.2, R3.2, U1.1, U1.2, U1.3, U1.6, U1.10, U1.11
unnamed: R3.1, U1.9

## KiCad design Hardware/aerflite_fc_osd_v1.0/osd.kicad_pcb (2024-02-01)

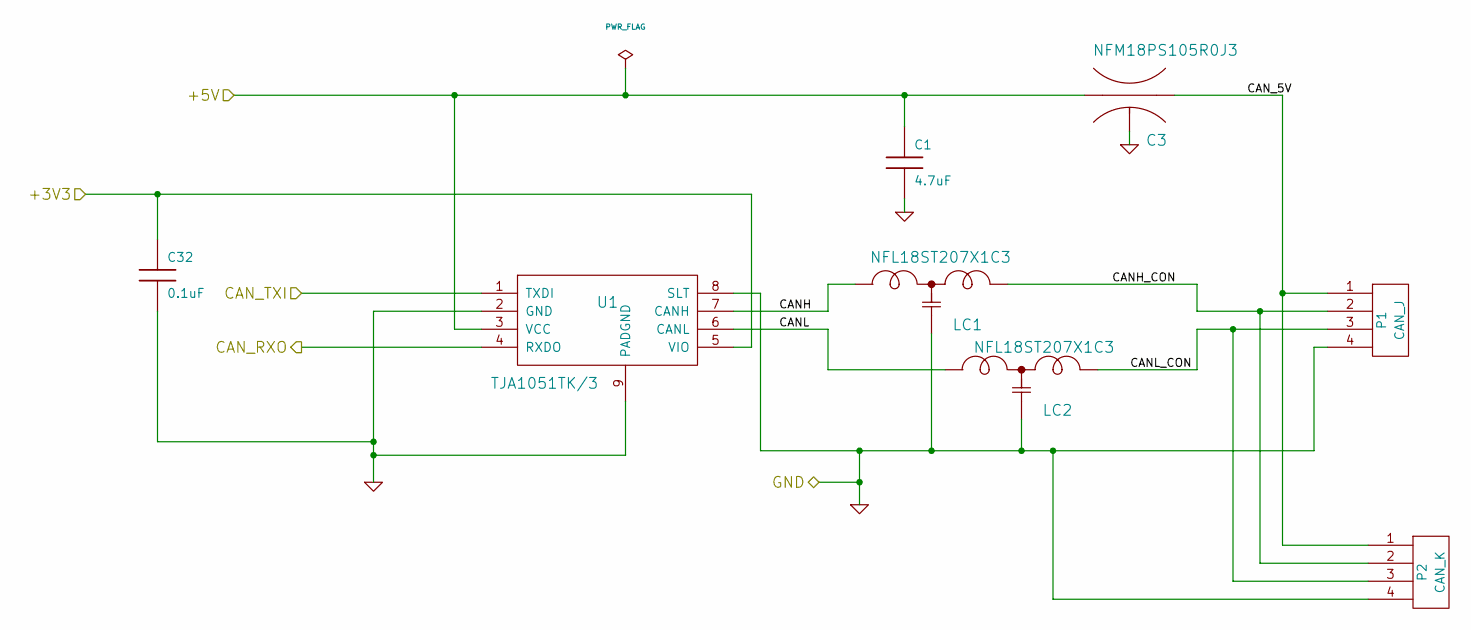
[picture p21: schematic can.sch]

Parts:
C1: 4.7uF; SMD_0603
C3: NFM18PS105R0J3; SMD_0603-3T_C_FILT_RND
C32: 0.1uF; SMD_0603
LC1, LC2: NFL18ST207X1C3; SMD_0603-3T_LC_FILT_RND
P1: CAN_J; JST_GH4_vert
P2: CAN_K; JST_GH4_horz
U1: TJA1051TK/3; SOT782-1

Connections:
/MCU/+3.3V: C32.1, U1.5 (VIO); also elsewhere on the board
/MCU/CAN_RX: U1.4 (RXDO); also elsewhere on the board
/MCU/CAN_TX: U1.1 (TXDI); also elsewhere on the board
/can/+5V: C1.1, C3.1 (IO1), U1.3 (VCC); also elsewhere on the board
/can/CANH: LC1.1 (Input), U1.7 (CANH)
/can/CANH_CON: LC1.3 (Output), P1.2, P2.2
/can/CANL: LC2.1 (Input), U1.6 (CANL)
/can/CANL_CON: LC2.3 (Output), P1.3, P2.3
/can/CAN_5V: C3.3 (IO2), P1.1, P2.1
GND: C1.2, C3.2 (GND), C32.2, LC1.2 (GND), LC2.2 (GND), P1.4, P2.4, U1.2 (GND), U1.8 (SLT), U1.9 (PADGND); also elsewhere on the board

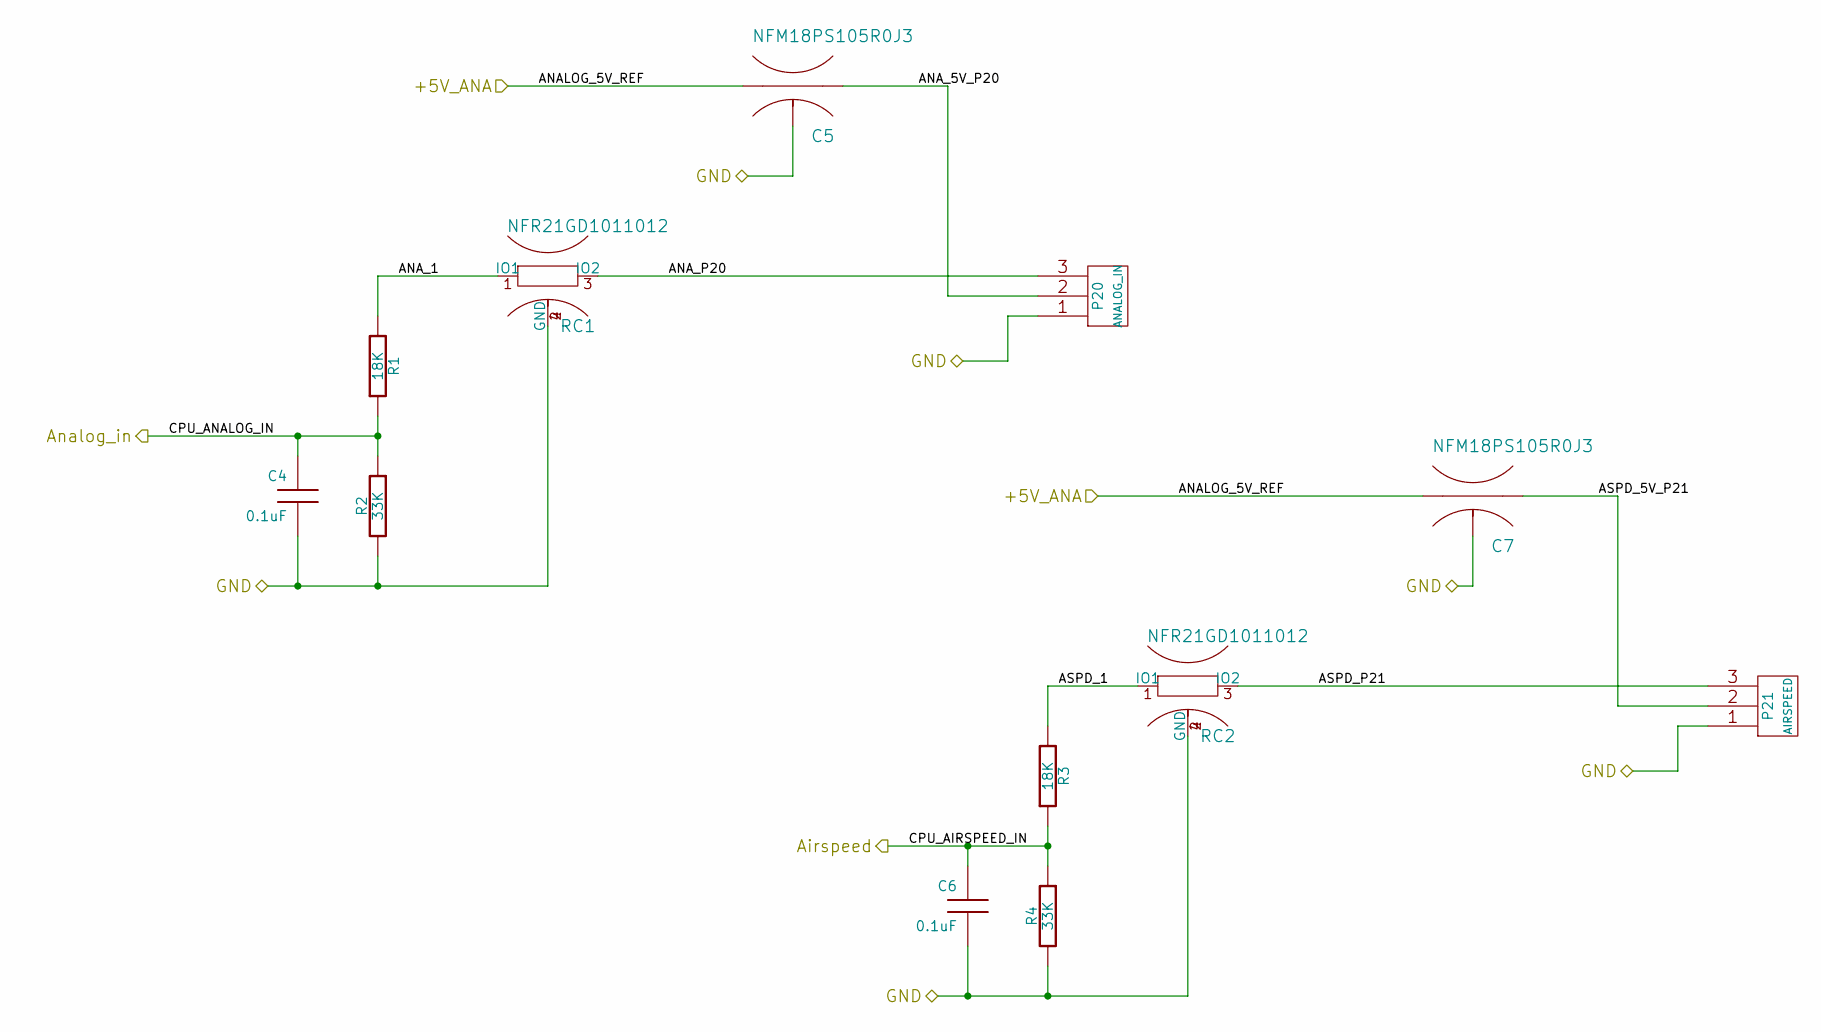
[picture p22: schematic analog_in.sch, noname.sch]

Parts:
C4, C6: 0.1uF; SMD_0603
C5, C7: NFM18PS105R0J3; SMD_0603-3T_C_FILT_RND
P20: ANALOG_IN; JST_GH3_vert
P21: AIRSPEED; JST_GH3_vert
R1, R3: 18K; SMD_0603
R2, R4: 33K; SMD_0603
RC1, RC2: NFR21GD1011012; NFR21G_RC_FILT

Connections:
/MCU/ADC2: C4.1, R1.1, R2.1; also elsewhere on the board
/MCU/ADC6: C6.1, R3.1, R4.1; also elsewhere on the board
/analog_in/+5V_ANA: C5.1 (IO1), C7.1 (IO1); also elsewhere on the board
/analog_in/ANA_1: R1.2, RC1.1 (IO1)
/analog_in/ANA_5V_P20: C5.3 (IO2), P20.2 (PM)
/analog_in/ANA_P20: P20.3, RC1.3 (IO2)
/analog_in/ASPD_1: R3.2, RC2.1 (IO1)
/analog_in/ASPD_5V_P21: C7.3 (IO2), P21.2 (PM)
/analog_in/ASPD_P21: P21.3, RC2.3 (IO2)
GND: C4.2, C5.2 (GND), C6.2, C7.2 (GND), P20.1, P21.1, R2.2, R4.2, RC1.2 (GND), RC1.4 (GND), RC2.2 (GND), RC2.4 (GND); also elsewhere on the board

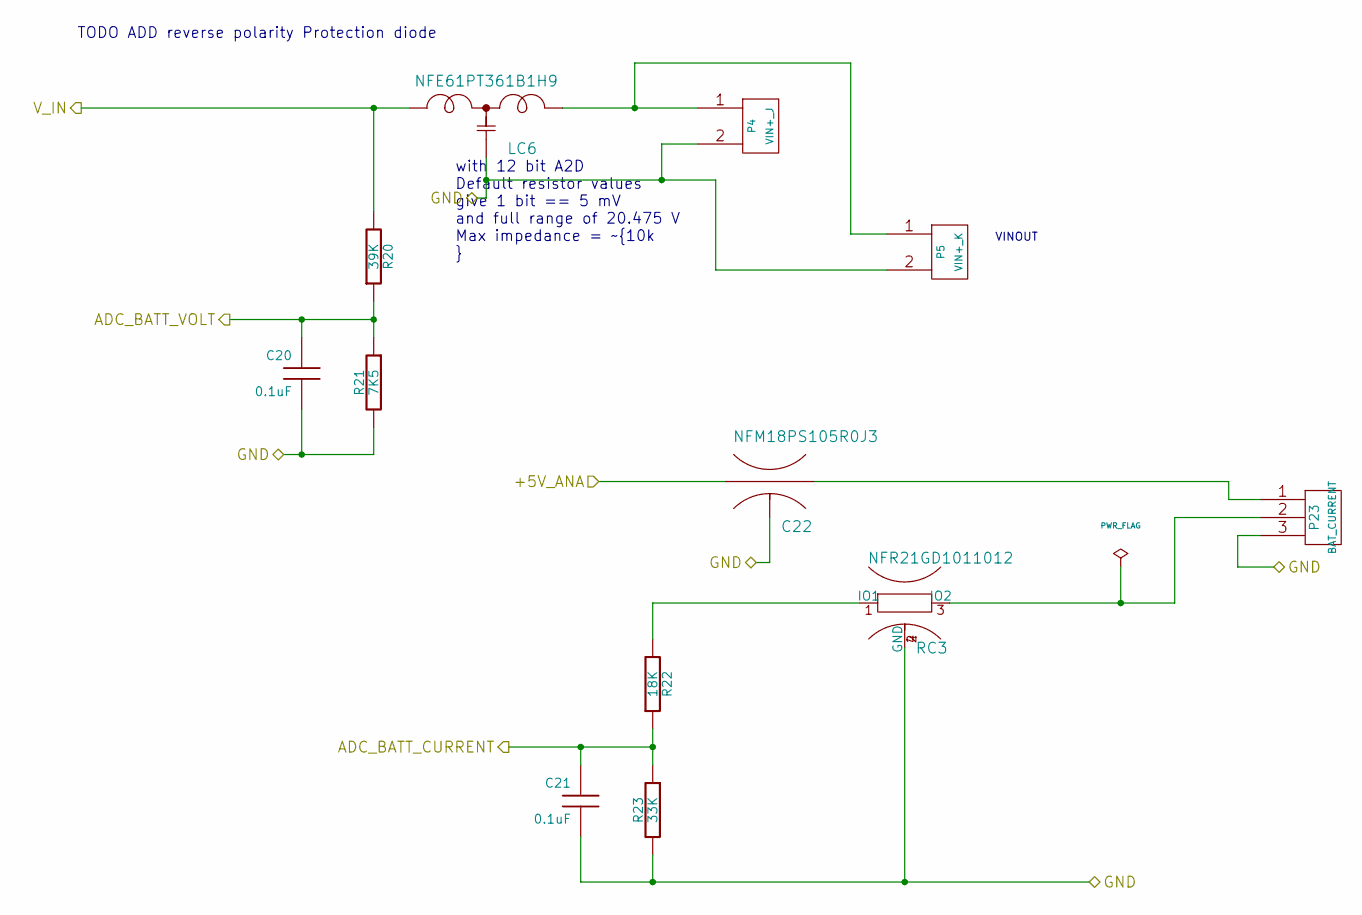
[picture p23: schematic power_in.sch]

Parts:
C20, C21: 0.1uF; SMD_0603
C22: NFM18PS105R0J3; SMD_0603-3T_C_FILT_RND
LC6: NFE61PT361B1H9; SMD_2706-3T_LC_FILT
P4: VIN+_J; JST_GH2_horz
P5: VIN+_K; JST_GH2_horz
P23: BAT_CURRENT; JST_GH3_vert
R20: 39K; SMD_0603
R21: 7K5; SMD_0603
R22: 18K; SMD_0603
R23: 33K; SMD_0603
RC3: NFR21GD1011012; NFR21G_RC_FILT

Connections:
/MCU/ADC4: C21.1, R22.1, R23.1; also elsewhere on the board
/MCU/ADC5: C20.1, R20.1, R21.1; also elsewhere on the board
/analog_in/+5V_ANA: C22.1 (IO1); also elsewhere on the board
/psu/VIN+: LC6.1 (Input), R20.2; also elsewhere on the board
GND: C20.2, C21.2, C22.2 (GND), LC6.2 (GND), P4.2 (PM), P5.2 (PM), P23.3, R21.2, R23.2, RC3.2 (GND), RC3.4 (GND); also elsewhere on the board
unnamed: C22.3 (IO2), P23.1
unnamed: LC6.3 (Output), P4.1, P5.1
unnamed: P23.2 (PM), RC3.3 (IO2)
unnamed: R22.2, RC3.1 (IO1)

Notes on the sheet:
VINOUT
with 12 bit A2D Default resistor values give 1 bit == 5 mV and full range of 20.475 V Max impedance = ~10k
TODO ADD reverse polarity Protection diode

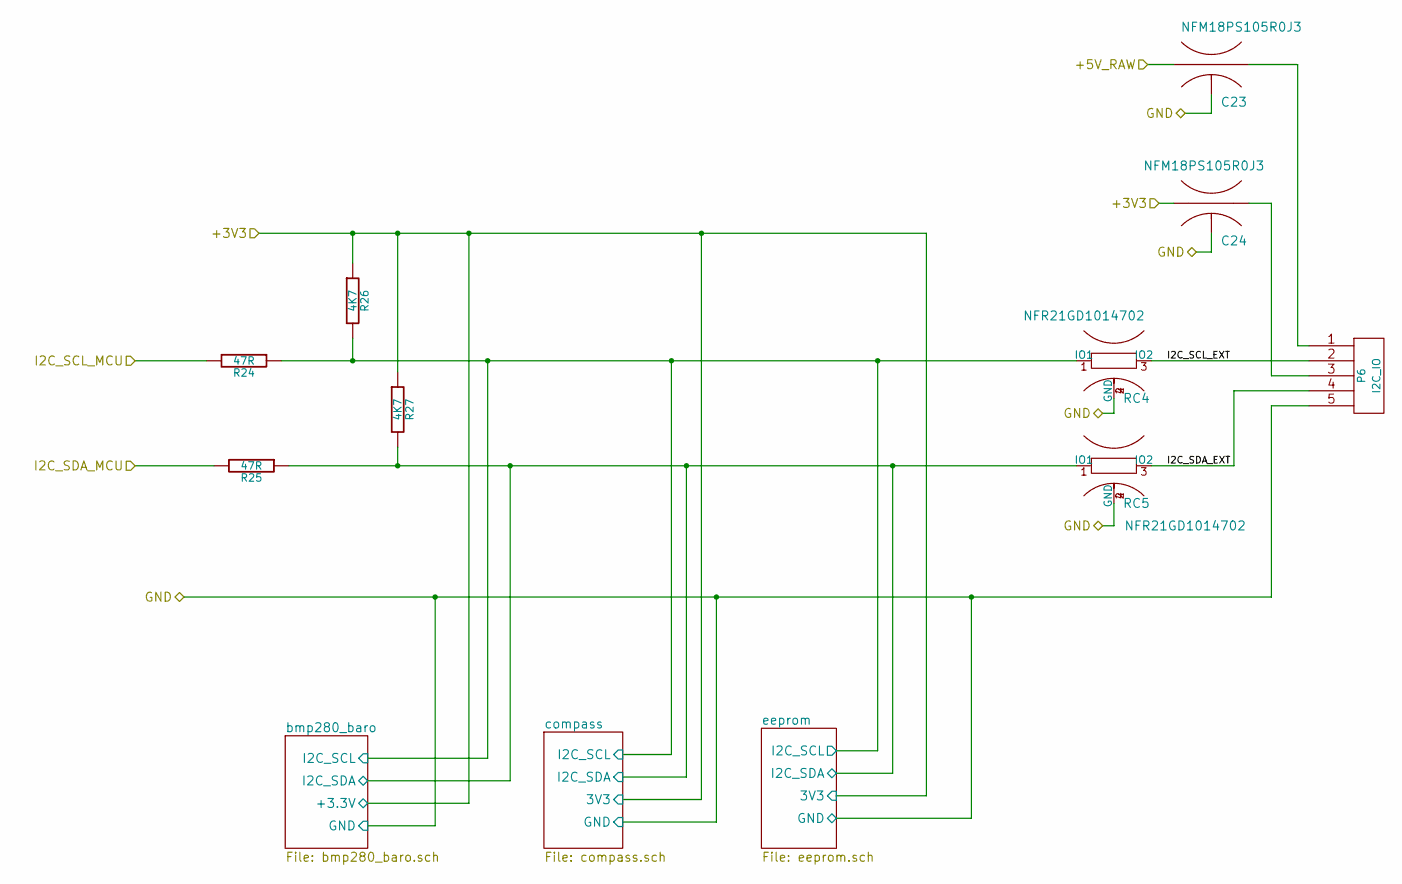
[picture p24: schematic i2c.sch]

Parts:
C23, C24: NFM18PS105R0J3; SMD_0603-3T_C_FILT_RND
P6: I2C_IO; JST_GH5_vert
R24, R25: 47R; SMD_0603
R26, R27: 4K7; SMD_0603
RC4, RC5: NFR21GD1014702; NFR21G_RC_FILT

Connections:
/MCU/+3.3V: C24.1 (IO1), R26.1, R27.1; also elsewhere on the board
/MCU/I2C_SCL_MCU: R24.2; also elsewhere on the board
/MCU/I2C_SDA_MCU: R25.2; also elsewhere on the board
/can/+5V: C23.1 (IO1); also elsewhere on the board
/i2c/I2C_SCL_EXT: P6.2, RC4.3 (IO2)
/i2c/I2C_SDA_EXT: P6.4, RC5.3 (IO2)
/i2c/bmp280_baro/I2C_SCL: R24.1, R26.2, RC4.1 (IO1); also elsewhere on the board
/i2c/bmp280_baro/I2C_SDA: R25.1, R27.2, RC5.1 (IO1); also elsewhere on the board
GND: C23.2 (GND), C24.2 (GND), P6.5, RC4.2 (GND), RC4.4 (GND), RC5.2 (GND), RC5.4 (GND); also elsewhere on the board
unnamed: C23.3 (IO2), P6.1
unnamed: C24.3 (IO2), P6.3

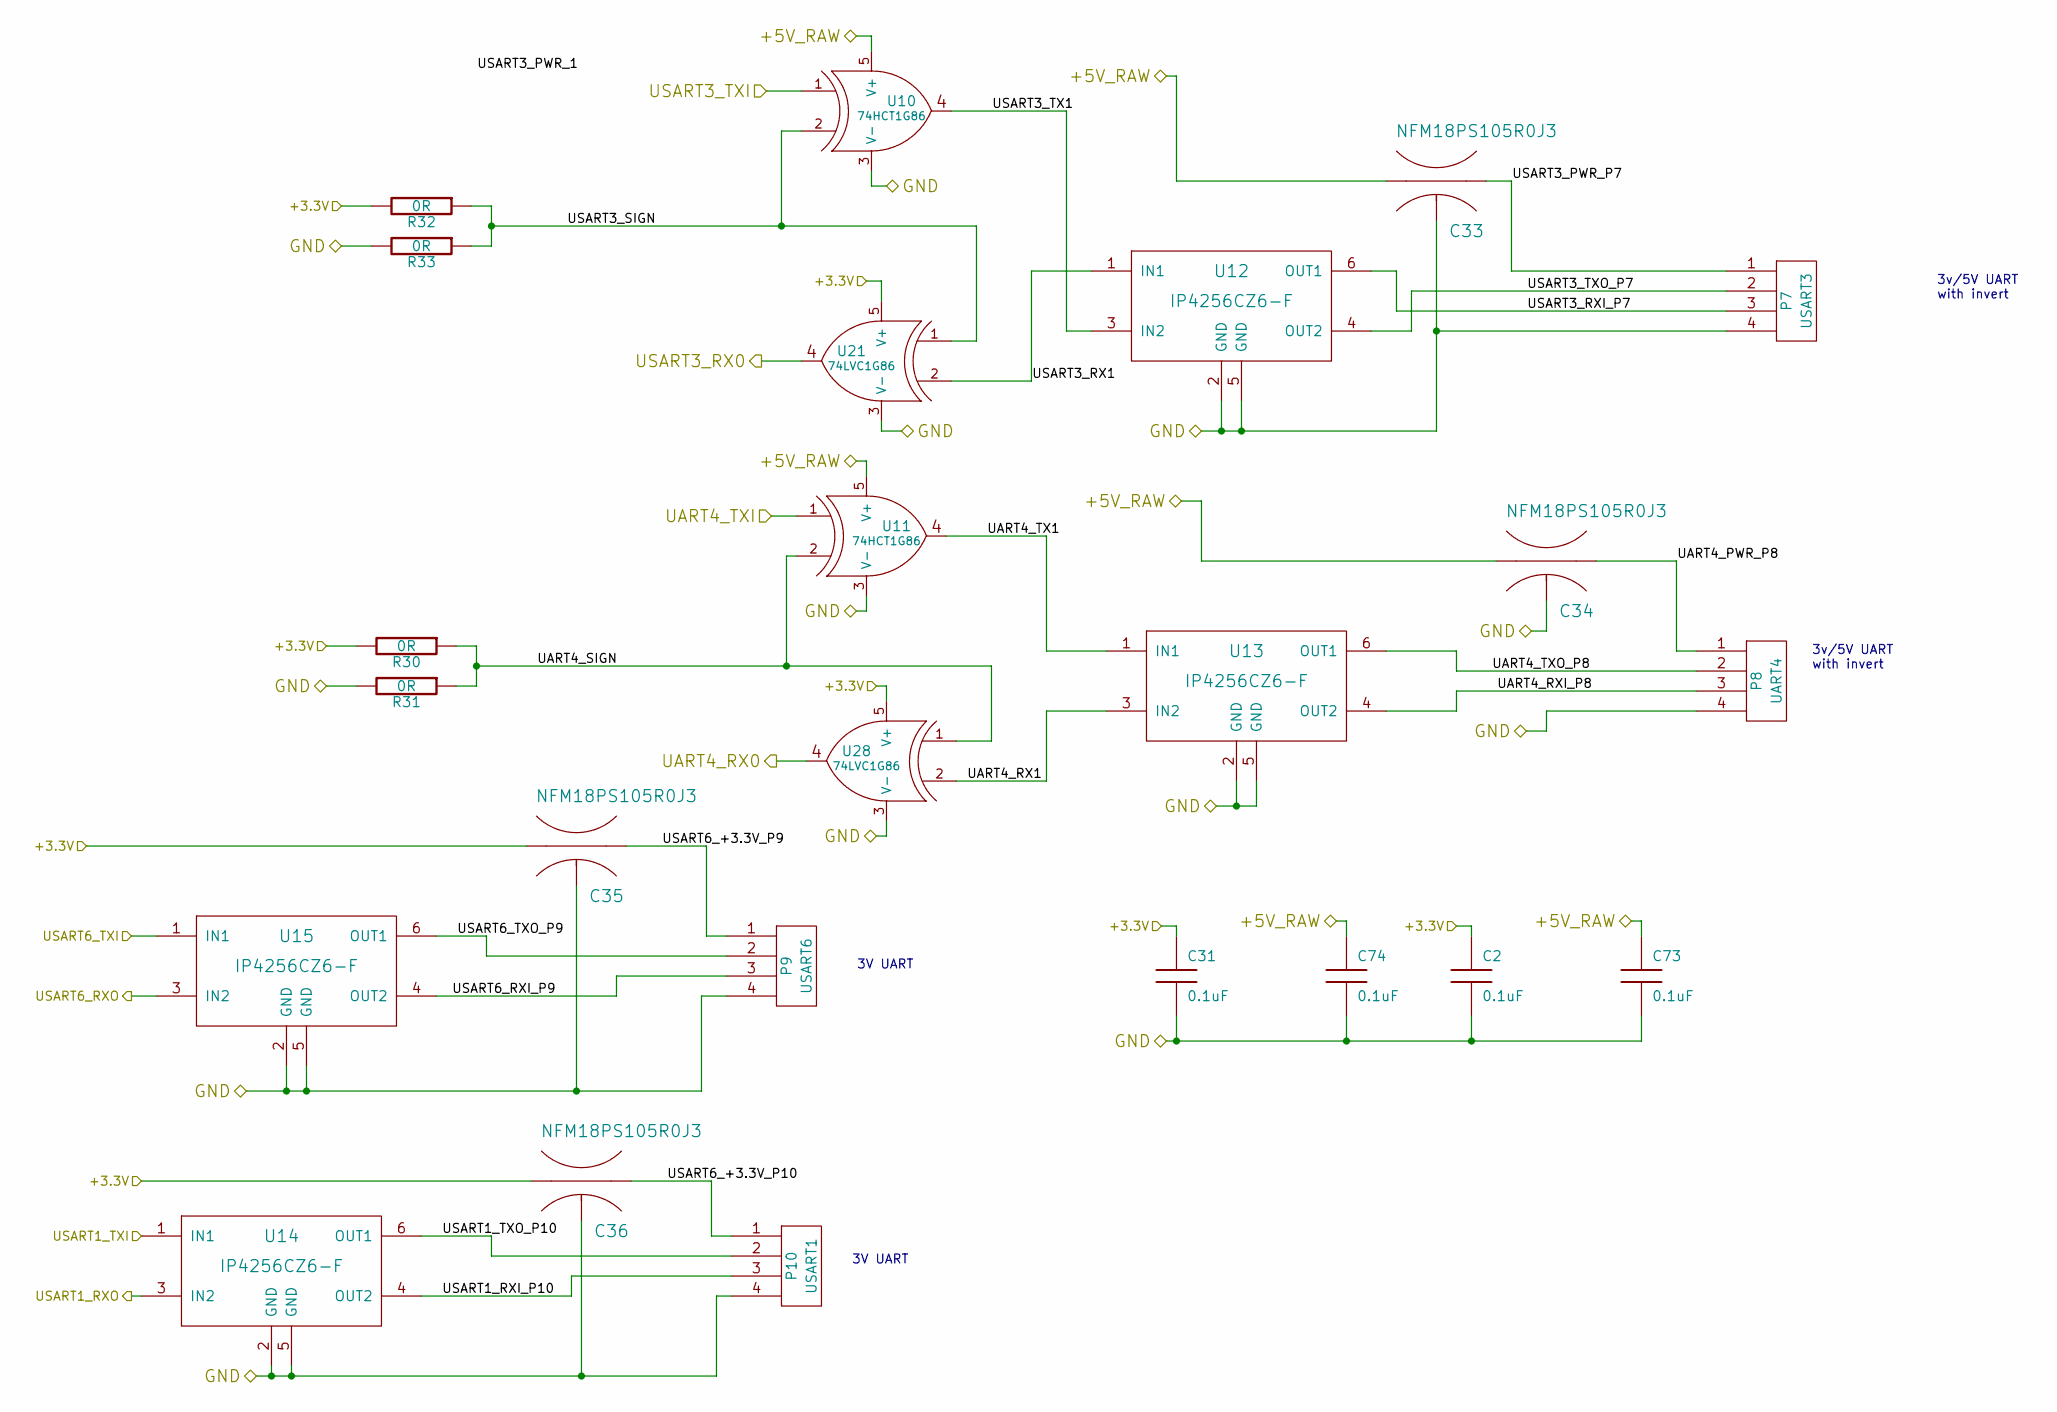
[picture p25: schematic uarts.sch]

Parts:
C2, C31, C73, C74: 0.1uF; SMD_0603
C33, C34, C35, C36: NFM18PS105R0J3; SMD_0603-3T_C_FILT_RND
P7: USART3; JST_GH4_vert
P8: UART4; JST_GH4_horz
P9: USART6; JST_GH4_vert
P10: USART1; JST_GH4_vert
R30, R31, R32, R33: 0R; SMD_0603
U10, U11: 74HCT1G86; SC70-5
U12, U13, U14, U15: IP4256CZ6-F; SOT886
U21, U28: 74LVC1G86; SC70-5

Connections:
/MCU/+3.3V: C2.1, C31.1, C35.1 (IO1), C36.1 (IO1), R30.2, R32.2, U21.5 (V+), U28.5 (V+); also elsewhere on the board
/MCU/USART1_RXI: U14.3 (IN2); also elsewhere on the board
/MCU/USART6_RXI: U15.3 (IN2); also elsewhere on the board
/can/+5V: C33.1 (IO1), C34.1 (IO1), C73.1, C74.1, U10.5 (V+), U11.5 (V+); also elsewhere on the board
/uarts/UART4_PWR_P8: C34.3 (IO2), P8.1
/uarts/UART4_RX0: U28.4; also elsewhere on the board
/uarts/UART4_RX1: U13.3 (IN2), U28.2
/uarts/UART4_RXI_P8: P8.3, U13.4 (OUT2)
/uarts/UART4_SIGN: R30.1, R31.1, U11.2, U28.1
/uarts/UART4_TX1: U11.4, U13.1 (IN1)
/uarts/UART4_TXI: U11.1; also elsewhere on the board
/uarts/UART4_TXO_P8: P8.2, U13.6 (OUT1)
/uarts/USART1_RXI_P10: P10.3, U14.4 (OUT2)
/uarts/USART1_TXI: U14.1 (IN1); also elsewhere on the board
/uarts/USART1_TXO_P10: P10.2, U14.6 (OUT1)
/uarts/USART3_PWR_P7: C33.3 (IO2), P7.1
/uarts/USART3_RX0: U21.4; also elsewhere on the board
/uarts/USART3_RX1: U12.1 (IN1), U21.2
/uarts/USART3_RXI_P7: P7.3, U12.6 (OUT1)
/uarts/USART3_SIGN: R32.1, R33.1, U10.2, U21.1
/uarts/USART3_TX1: U10.4, U12.3 (IN2)
/uarts/USART3_TXI: U10.1; also elsewhere on the board
/uarts/USART3_TXO_P7: P7.2, U12.4 (OUT2)
/uarts/USART6_+3.3V_P9: C35.3 (IO2), P9.1
/uarts/USART6_+3.3V_P10: C36.3 (IO2), P10.1
/uarts/USART6_RXI_P9: P9.3, U15.4 (OUT2)
/uarts/USART6_TXI: U15.1 (IN1); also elsewhere on the board
/uarts/USART6_TXO_P9: P9.2, U15.6 (OUT1)
GND: C2.2, C31.2, C33.2 (GND), C34.2 (GND), C35.2 (GND), C36.2 (GND), C73.2, C74.2, P7.4, P8.4, P9.4, P10.4, R31.2, R33.2, U10.3 (V-), U11.3 (V-), U12.2 (GND), U12.5 (GND), U13.2 (GND), U13.5 (GND), U14.2 (GND), U14.5 (GND), U15.2 (GND), U15.5 (GND), U21.3 (V-), U28.3 (V-); also elsewhere on the board

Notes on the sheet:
3v/5V UART with invert
3V UART

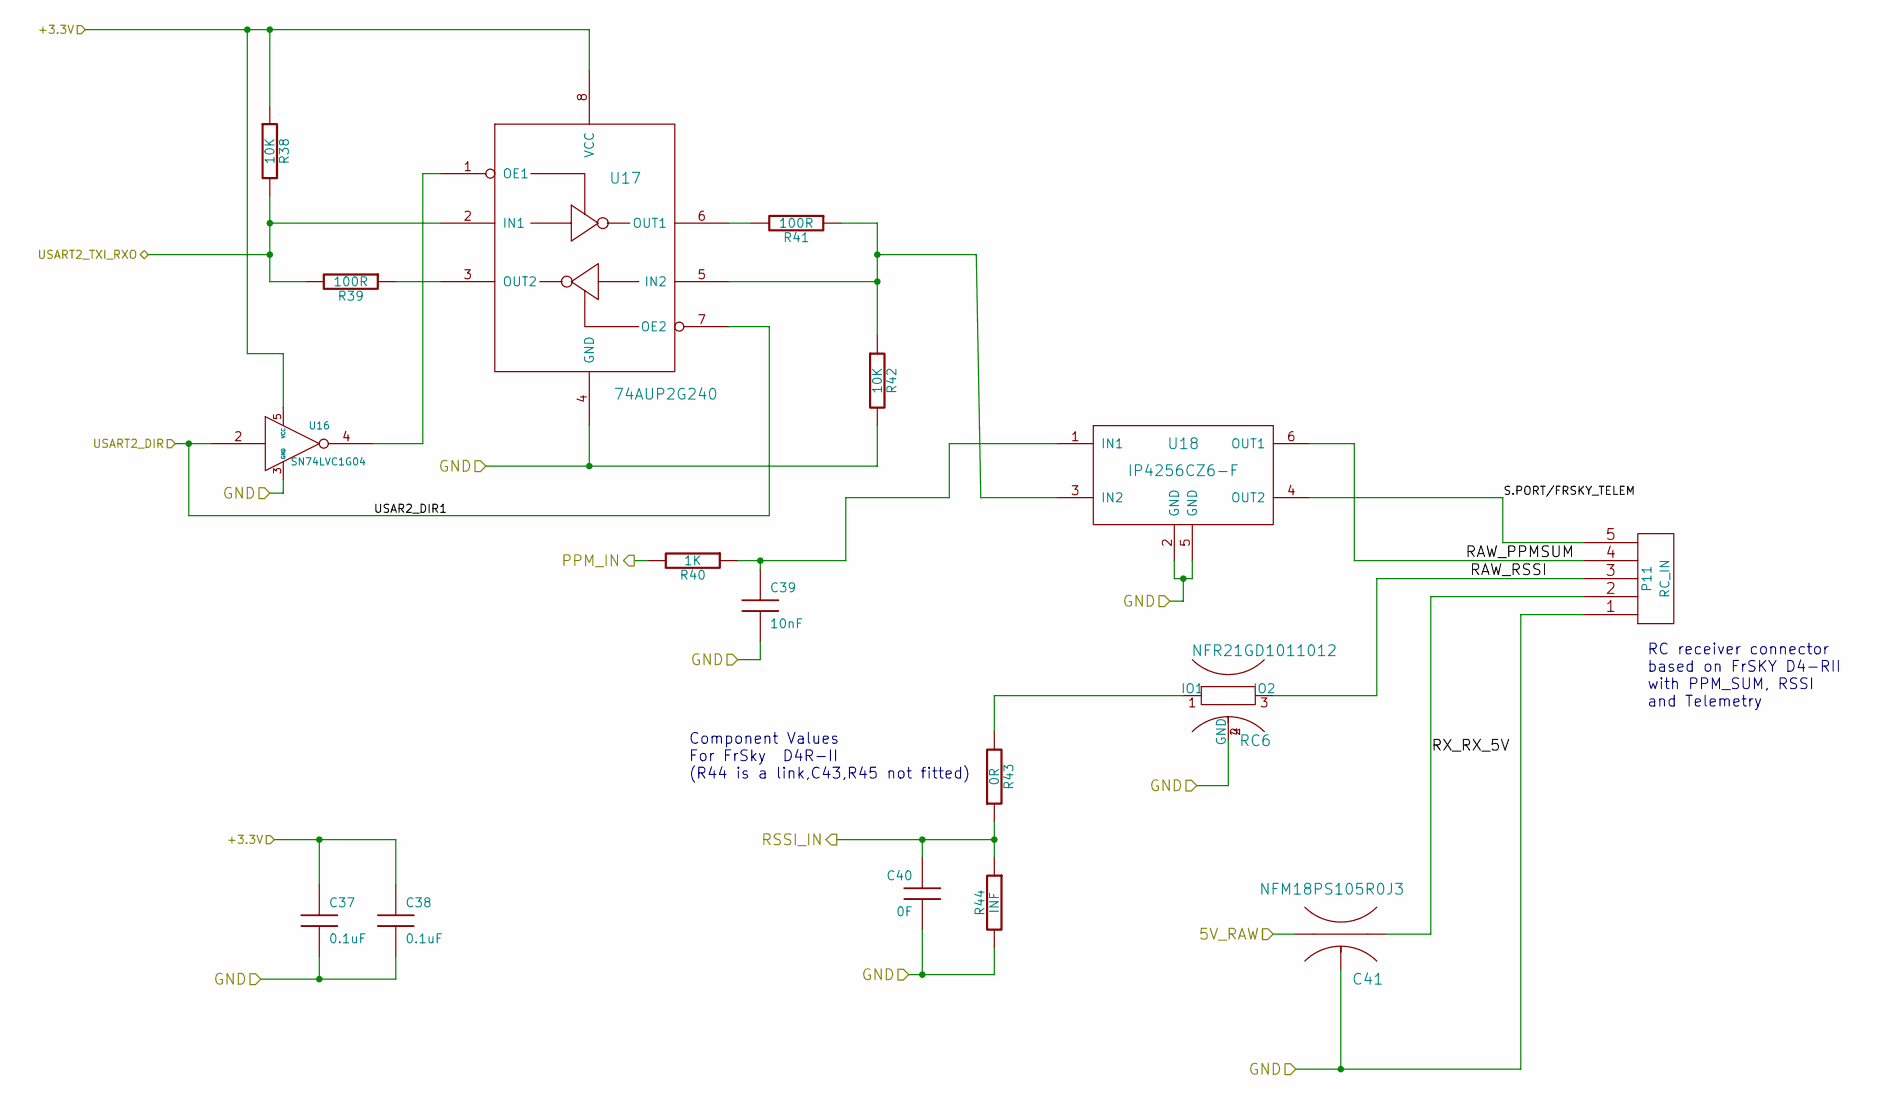
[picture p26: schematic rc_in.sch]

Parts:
C37, C38: 0.1uF; SMD_0603
C39: 10nF; SMD_0603
C40: 0F; SMD_0603
C41: NFM18PS105R0J3; SMD_0603-3T_C_FILT_RND
P11: RC_IN; JST_GH5_vert
R38, R42: 10K; SMD_0603
R39, R41: 100R; SMD_0603
R40: 1K; SMD_0603
R43: 0R; SMD_0603
R44: INF; SMD_0603
RC6: NFR21GD1011012; NFR21G_RC_FILT
U16: SN74LVC1G04; SC70-5
U17: 74AUP2G240; VSSOP8
U18: IP4256CZ6-F; SOT886

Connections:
/MCU/+3.3V: C37.1, C38.1, R38.1, U16.5 (VCC), U17.8 (VCC); also elsewhere on the board
/MCU/ADC3: C40.1, R43.1, R44.1; also elsewhere on the board
/MCU/PPMSUM_IN: R40.2; also elsewhere on the board
/MCU/USART2_DIR: U16.2, U17.7 (OE2); also elsewhere on the board
/can/+5V: C41.1 (IO1); also elsewhere on the board
/rc_in/RAW_PPMSUM: P11.4, U18.6 (OUT1)
/rc_in/RAW_RSSI: P11.3, RC6.3 (IO2)
/rc_in/RX_RX_5V: C41.3 (IO2), P11.2
/rc_in/S.PORT/FRSKY_TELEM: P11.5, U18.4 (OUT2)
/rc_in/USART2_TXI_RXO: R38.2, R39.2, U17.2 (IN1); also elsewhere on the board
GND: C37.2, C38.2, C39.2, C40.2, C41.2 (GND), P11.1, R42.2, R44.2, RC6.2 (GND), RC6.4 (GND), U16.3 (GND), U17.4 (GND), U18.2 (GND), U18.5 (GND); also elsewhere on the board
unnamed: C39.1, R40.1, U18.1 (IN1)
unnamed: R39.1, U17.3 (OUT2)
unnamed: R41.1, R42.1, U17.5 (IN2), U18.3 (IN2)
unnamed: R41.2, U17.6 (OUT1)
unnamed: R43.2, RC6.1 (IO1)
unnamed: U16.4, U17.1 (OE1)

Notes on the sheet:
Component Values For FrSky D4R-II (R44 is a link,C43,R45 not fitted)
RC receiver connector based on FrSKY D4-RII with PPM_SUM, RSSI and Telemetry

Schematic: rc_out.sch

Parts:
C42, C43: 0.1uF; SMD_0603
P12: RCOUT_5V; EDGE_HDR_01_6
P13: RCOUT_SIG; EDGE_HDR_01_6
P17, P18: CONN_1; TP
U19: SI8065; QSSOP16

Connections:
/MCU/+3.3V: C42.1, U19.1 (VDD1); also elsewhere on the board
/MCU/RCOUT_1: U19.7 (A6); also elsewhere on the board
/MCU/RCOUT_2: U19.6 (A5); also elsewhere on the board
/MCU/RCOUT_3: U19.5 (A4); also elsewhere on the board
/MCU/RCOUT_4: U19.4 (A3); also elsewhere on the board
/MCU/RCOUT_5: U19.3 (A2); also elsewhere on the board
/MCU/RCOUT_6: U19.2 (A1); also elsewhere on the board
/rc_out/5V_EXT: C43.1, P12.1, P12.2, P12.3, P12.4, P12.5, P12.6, U19.16 (VDD2)
/rc_out/GND_EXT: C43.2, P17.1, P18.1, U19.9 (GND2)
GND: C42.2, U19.8 (GND1); also elsewhere on the board
unnamed: P13.1, U19.10 (B6)
unnamed: P13.2, U19.11 (B5)
unnamed: P13.3, U19.12 (B4)
unnamed: P13.4, U19.13 (B3)
unnamed: P13.5, U19.14 (B2)
unnamed: P13.6, U19.15 (B1)

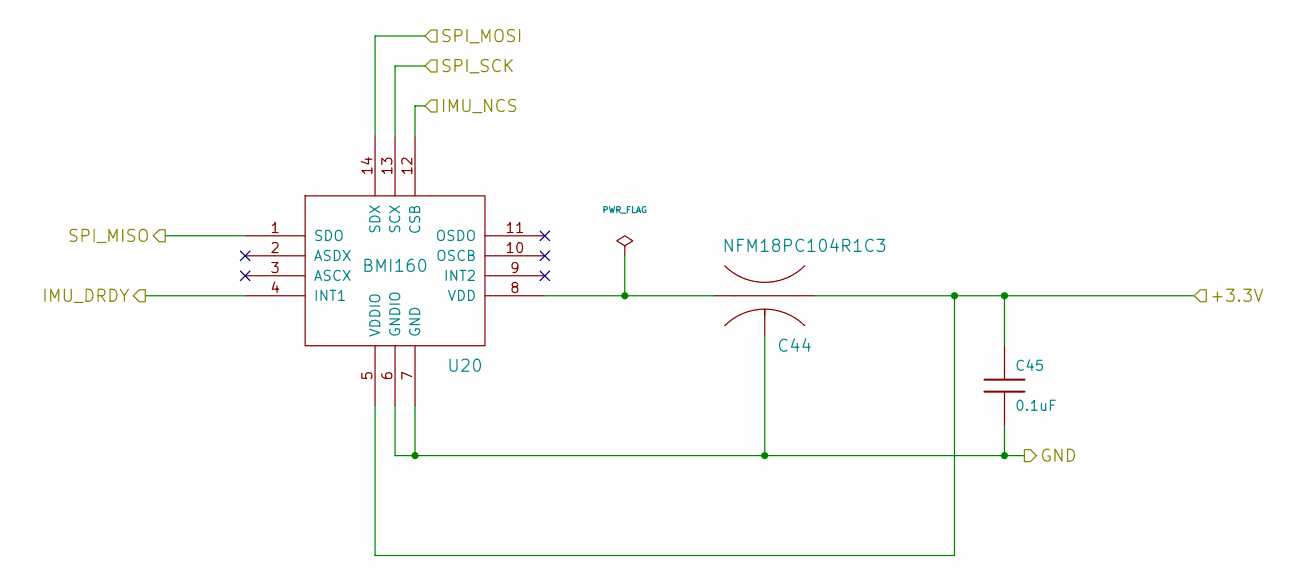
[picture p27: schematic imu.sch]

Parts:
C44: NFM18PC104R1C3; SMD_0603-3T_LC_FILT_RND
C45: 0.1uF; SMD_0603
U20: BMI160

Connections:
/MCU/+3.3V: C44.3 (IO2), C45.1, U20.5 (VDDIO); also elsewhere on the board
/MCU/SPI_MISO: U20.1 (SDO); also elsewhere on the board
/MCU/SPI_MOSI: U20.14 (SDX); also elsewhere on the board
/MCU/SPI_SCK: U20.13 (SCX); also elsewhere on the board
/imu/IMU_DRDY: U20.4 (INT1); also elsewhere on the board
/imu/IMU_NCS: U20.12 (CSB); also elsewhere on the board
GND: C44.2 (GND), C45.2, U20.6 (GNDIO), U20.7 (GND); also elsewhere on the board
unnamed: C44.1 (IO1), U20.8 (VDD)

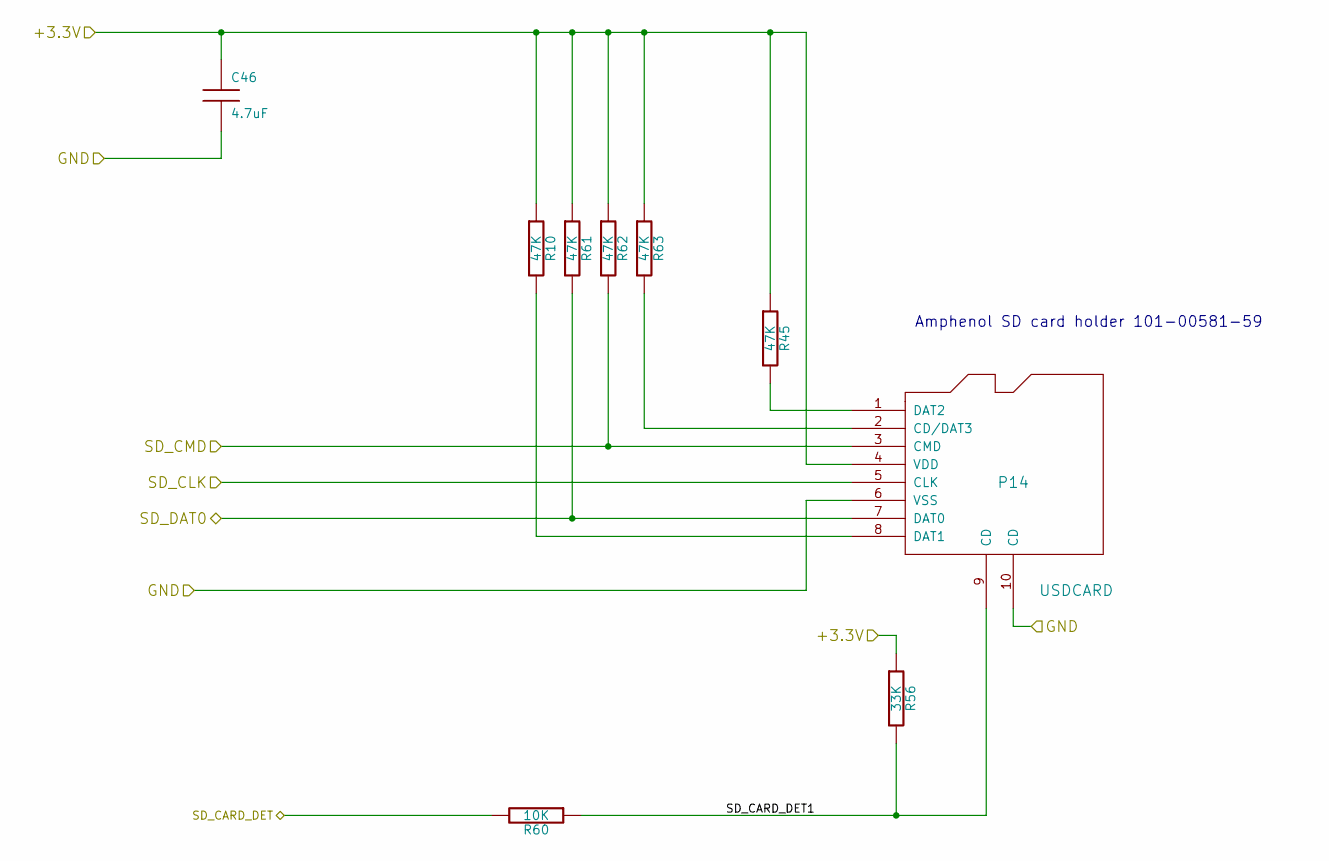
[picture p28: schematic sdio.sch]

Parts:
C46: 4.7uF; SMD_0603
P14: USDCARD; uSD_Molex_503182
R10, R45, R61, R62, R63: 47K; SMD_0603
R56: 33K; SMD_0603
R60: 10K; SMD_0603

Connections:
/MCU/+3.3V: C46.1, P14.4 (VDD), R10.1, R45.1, R56.1, R61.1, R62.1, R63.1; also elsewhere on the board
/MCU/SDIO_CMD: P14.3 (CMD), R62.2; also elsewhere on the board
/MCU/SDIO_D0: P14.7 (DAT0), R61.2; also elsewhere on the board
/MCU/SDIO_SCK: P14.5 (CLK); also elsewhere on the board
/MCU/SD_CARD_DET: R60.2; also elsewhere on the board
/sdio/SD_CARD_DET1: P14.9 (CD), R56.2, R60.1
GND: C46.2, P14.6 (VSS), P14.10 (CD); also elsewhere on the board
unnamed: P14.1 (DAT2), R45.2
unnamed: P14.2 (CD/DAT3), R63.2
unnamed: P14.8 (DAT1), R10.2

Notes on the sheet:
Amphenol SD card holder 101-00581-59

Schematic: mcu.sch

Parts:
C48: 1uF; SMD_0603
C49, C53, C54, C55, C56, C57: 0.1uF; SMD_0603; MFG Part Num P
C50: 0.1uF; SMD_0603
C51, C52: 2.2uF; SMD_0603; MFG Part Num P
C58, C59: 4.7uF; SMD_0603; MFG Part Num P
D1, D2, D3: Red_Led; LED_0603_IPC-7351_2005; MFG Part Num P
L3: BLM18SG331TN1; SMD_0603
P15: JTAG; JST_SH1_4_vert
P16: PROG; JST_SH1_2_vert
Q2: Si1922EDH; SC70-6
R46, R48: 10K; SMD_0603; MFG Part Num P
R47: 100R; SMD_0603
R49, R50, R51, R52: 470R; SMD_0603; MFG Part Num P
U22: CSTCE8M00GH5C99; MURATA_CSTCE
U23: 74LVC1G3157; SC70-6
U24: STM32F405RGT6; LQFP64; MFG Part Num STM32F405RGT6

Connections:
/MCU/+3.3V: C49.1, C53.1, C55.1, C56.1, C57.1, C58.1, C59.1, L3.1, P16.1, R48.1, R50.1, R51.1, U23.5 (V+), U24.1 (VBAT), U24.19 (VDD), U24.32 (VDD), U24.48 (VDD), U24.64 (VDD); also elsewhere on the board
/MCU/ADC1: U24.8 (PC0); also elsewhere on the board
/MCU/ADC2: U24.9 (PC1); also elsewhere on the board
/MCU/ADC3: U24.10 (PC2); also elsewhere on the board
/MCU/ADC4: U24.11 (PC3); also elsewhere on the board
/MCU/ADC5: U24.24 (PC4); also elsewhere on the board
/MCU/ADC6: U24.25 (PC5); also elsewhere on the board
/MCU/BOOT0_IN: P16.2 (PM), R52.1, U24.60 (BOOT0)
/MCU/CAN_RX: U24.44 (PA11); also elsewhere on the board
/MCU/CAN_TX: U24.45 (PA12); also elsewhere on the board
/MCU/CSYNC: U23.3 (NC), U24.21 (PA5), U24.36 (PB15); also elsewhere on the board
/MCU/DAC_OUT1: U24.20 (PA4); also elsewhere on the board
/MCU/I2C_SCL_MCU: U24.41 (PA8); also elsewhere on the board
/MCU/I2C_SDA_MCU: U24.40 (PC9); also elsewhere on the board
/MCU/ISYNC: R46.2, U23.6 (A0), U24.28 (PB2/BOOT1); also elsewhere on the board
/MCU/LED1_LED: D1.2 (An), R49.2
/MCU/LED1_MPU: R49.1, U24.33 (PB12)
/MCU/LED2_ANODE: D2.1 (Ca), Q2.6 (D)
/MCU/LED2_CATHODE: D2.2 (An), R50.2
/MCU/LED3_ANODE: D3.1 (Ca), Q2.3 (D)
/MCU/LED3_CATHODE: D3.2 (An), R51.2
/MCU/MASK: R47.1, U24.35 (PB14); also elsewhere on the board
/MCU/MCU_VDDA: C48.1, C50.1, L3.2, U24.13 (VDDA)
/MCU/NRST: C54.1, P15.4, R48.2, U24.7 (NRST)
/MCU/OSC_IN: U22.1 (RES1), U24.5 (PH0/OSC_IN)
/MCU/OSC_OUT: U22.3 (RES2), U24.6 (PH1/OSC_OUT)
/MCU/PIXEL_CLK: U24.17 (PA3), U24.34 (PB13), U24.51 (PC10)
/MCU/PPMSUM_IN: U24.23 (PA7); also elsewhere on the board
/MCU/RCOUT_1: U24.58 (PB6); also elsewhere on the board
/MCU/RCOUT_2: U24.59 (PB7); also elsewhere on the board
/MCU/RCOUT_3: U24.61 (PB8); also elsewhere on the board
/MCU/RCOUT_4: U24.62 (PB9); also elsewhere on the board
/MCU/RCOUT_5: U24.26 (PB0); also elsewhere on the board
/MCU/RCOUT_6: U24.27 (PB1); also elsewhere on the board
/MCU/SDIO_CMD: U24.54 (PD2); also elsewhere on the board
/MCU/SDIO_D0: U24.39 (PC8); also elsewhere on the board
/MCU/SDIO_SCK: U24.53 (PC12); also elsewhere on the board
/MCU/SD_CARD_DET: U24.4 (PC15); also elsewhere on the board
/MCU/SPI_MISO: U24.56 (PB4); also elsewhere on the board
/MCU/SPI_MOSI: U24.57 (PB5); also elsewhere on the board
/MCU/SPI_SCK: U24.55 (PB3); also elsewhere on the board
/MCU/SWCLK: P15.2, Q2.5 (G), U24.49 (PA14)
/MCU/SWDIO: P15.3, Q2.2 (G), U24.46 (PA13)
/MCU/SYNC_SRC_SW: U23.4 (COM), U24.22 (PA6)
/MCU/USART1_RXI: U24.43 (PA10); also elsewhere on the board
/MCU/USART2_DIR: U24.3 (PC14); also elsewhere on the board
/MCU/USART6_RXI: U24.38 (PC7); also elsewhere on the board
/MCU/VCAP1: C51.1, U24.31 (VCAP_1)
/MCU/VCAP_2: C52.1, U24.47 (VCAP_2)
/imu/IMU_DRDY: U24.2 (PC13); also elsewhere on the board
/imu/IMU_NCS: U24.50 (PA15); also elsewhere on the board
/rc_in/USART2_TXI_RXO: U24.16 (PA2); also elsewhere on the board
/uarts/UART4_RX0: U24.15 (PA1); also elsewhere on the board
/uarts/UART4_TXI: U24.14 (PA0); also elsewhere on the board
/uarts/USART1_TXI: U24.42 (PA9); also elsewhere on the board
/uarts/USART3_RX0: U24.30 (PB11); also elsewhere on the board
/uarts/USART3_TXI: U24.29 (PB10); also elsewhere on the board
/uarts/USART6_TXI: U24.37 (PC6); also elsewhere on the board
/video/LEVEL: U24.52 (PC11); also elsewhere on the board
GND: C48.2, C49.2, C50.2, C51.2, C52.2, C53.2, C54.2, C55.2, C56.2, C57.2, C58.2, C59.2, D1.1 (Ca), P15.1, Q2.1 (S), Q2.4 (S), R46.1, R52.2, U22.2 (GND), U23.2 (GND), U24.12 (VSSA), U24.18 (VSS), U24.63 (VSS); also elsewhere on the board
unnamed: R47.2, U23.1 (NO)

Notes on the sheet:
USART3_TXO
TIM1_CH3N
TIM1_CH2N
ADC1_IN5
ADC1_IN4
TIM14_CH1
Use resonator Murata CSTCE8M00GH5C99-R0 TODO
TIM3_CH1
I2C3_SDA
I2C3_SCL
SPI2_MISO
SPI1_SCK
SPI1_MISO
Prog Connector
SWCLK
SWDIO
USART1_TX
USART1_RX
SPI3_MISO
SDIO_CMD
TIM2_CH1
SPI3_SCK (WHITE)
TIM12_CH2
SPI2_CLK

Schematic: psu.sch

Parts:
C47: 22uF; SMD_0805
C60: NFM21PC104R1E3; NFM21CC
C61: 4.7uF; SMD_0805; MFG Part Num P
C62: 0.1uF; SMD_0603
C63: 15nF; SMD_0603; MFG Part Num P
C64, C67: 1uF; SMD_0603
C66, C69: NFM18PS105D0J3; SMD_0603-3T_C_FILT_RND
C68: 22uF; C_1210; MFG Part Num P
C70: 22uF; SMD_0805; MFG Part Num P
C71: 0.1uF; SMD_0603; MFG Part Num P
D4: SSA33L; DO-214AC; MFG Part Num MBR0530T1G
D5: SSA33L; DO-214AC
D6: Blue_Led; LED_0603_IPC-7351_2005; MFG Part Num P
L1: 10uH; CLF7045T; MFG Part Num CLF7045T-100M-D
P19: 5V_OUT; JST_GH3_vert
R53: 53K6; SMD_0603; MFG Part Num P
R54: 9K1; SMD_0603; MFG Part Num P
R55: 470R; SMD_0603; MFG Part Num P
U25: ADP2302; SOIC8-TPAD
U26: MCP1700; SOT23-3
U27: uA78M33; SOT223_2p

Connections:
/MCU/+3.3V: C70.1, C71.1, U27.3, U27.VO; also elsewhere on the board
/analog_in/+5V_ANA: C64.1, U26.2 (VOUT); also elsewhere on the board
/can/+5V: C47.1, C67.1, C69.1 (IO1), D5.1 (Ca); also elsewhere on the board
/psu/+5.5V: C62.1, C66.3 (IO2), D5.2 (An), U26.3 (VIN), U27.1, U27.VI
/psu/SWITCHER_+5V: C66.1 (IO1), C68.1, D6.2 (An), L1.1, R53.1
/psu/SWITCHER_BST: C63.1, U25.1 (BST)
/psu/SWITCHER_FB: R53.2, R54.1, U25.5 (FB)
/psu/SWITCHER_SW: C63.2, D4.1 (Ca), L1.2, U25.8 (SW)
/psu/VIN+: C60.1 (IO1); also elsewhere on the board
/psu/VIN+SW: C60.3 (IO2), C61.1, U25.2 (VIN), U25.3 (EN)
GND: C47.2, C60.2 (GND), C61.2, C62.2, C64.2, C66.2 (GND), C67.2, C68.2, C69.2 (GND), C70.2, C71.2, D4.2 (An), P19.3, R54.2, R55.2, U25.7 (GND), U25.9 (EPAD), U26.1 (GND), U27.2, U27.GND; also elsewhere on the board
unnamed: C69.3 (IO2), P19.1
unnamed: D6.1 (Ca), R55.1

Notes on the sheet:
5V OUT
0.6 W
250 mA
500 mA @ 5V

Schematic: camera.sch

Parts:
C8: NFM21PC104R1E3; NFM21CC
LC3: NFL18ST207X1C3; SMD_0603-3T_LC_FILT_RND
P22: VIDEO_IN; JST_GH3_horz

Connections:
/psu/VIN+: C8.3 (IO2); also elsewhere on the board
/video/camera/VIDEO_IN: LC3.3 (Output); also elsewhere on the board
/video/camera/VIDEO_IN_P22: LC3.1 (Input), P22.3
/video/camera/VIN+P22: C8.1 (IO1), P22.2 (PM)
GND: C8.2 (GND), LC3.2 (GND), P22.1; also elsewhere on the board

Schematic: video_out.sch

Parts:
C9, C75: 0.1uF; SMD_0603
C10: 33uF; SMD_0805; MFG Part Num P
C11: NFM21PC104R1E3; NFM21CC
LC4, LC5: NFL18ST207X1C3; SMD_0603-3T_LC_FILT_RND
P3: VIDEO_OUT; JST_GH4_horz
R5, R35: 75R; SMD_0603
R34: 24R; SMD_0603
U2: MCP6L01RT; SOT23-5
U29: MAX4390-SC70-6; SC70-6

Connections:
/MCU/DAC_OUT1: U2.3 (+); also elsewhere on the board
/can/+5V: C9.1, C75.1, U2.2 (VDD), U29.6 (V+); also elsewhere on the board
/psu/VIN+: C11.1 (IO1); also elsewhere on the board
/video/video_circuit/OSD_VIDEO_OUT: U29.3 (+); also elsewhere on the board
/video/video_out/AUDIO_OUT: C10.2, R5.1
/video/video_out/AUDIO_OUT_AC: C10.1, LC5.1 (Input)
/video/video_out/AUDIO_OUT_CON: LC5.3 (Output), P3.4
/video/video_out/AUDIO_OUT_RAW: R5.2, U2.1, U2.4 (-)
/video/video_out/VIDEO_OUT_BUF: R34.1, R35.2, U29.1
/video/video_out/VIDEO_OUT_CON: LC4.3 (Output), P3.3
/video/video_out/VIN+P3: C11.3 (IO2), P3.2
GND: C9.2, C11.2 (GND), C75.2, LC4.2 (GND), LC5.2 (GND), P3.1, U2.5 (VSS), U29.2 (V-); also elsewhere on the board
unnamed: LC4.1 (Input), R35.1
unnamed: R34.2, U29.4 (-)

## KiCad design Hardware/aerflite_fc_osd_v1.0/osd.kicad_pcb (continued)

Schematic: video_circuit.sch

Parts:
C12, C76: 0.1uF; SMD_0603
C13: 240pF; SMD_0603; MFG Part Num P
C14: NFM18PC104R1C3; SMD_0603-3T_C_FILT_RND
C15, C18, C19: 0.1uF; SMD_0603; MFG Part Num P
C16, C17: 4.7uF; SMD_0603; MFG Part Num P
C72: 1uF; SMD_0603
L2: BLM18SG331TN1; SMD_0603
Q1: MMUN2211LT1-D; SOT23-3
R6: 1K5; SMD_0603; MFG Part Num P
R7: 1K; SMD_0603; MFG Part Num P
R8: 560R; SMD_0603
R9, R16: 150R; SMD_0603
R12: 1.2K; SMD_0603; MFG Part Num P
R13: 100R; SMD_0603
R14, R19: 68R; SMD_0603
R15: 3K3; SMD_0603; MFG Part Num P
R17: 240R; SMD_0603
R18: 200R; SMD_0603
U3: MCP6562; MSOP-8; MFG Part Num MCP6562-E/MS
U4: FMS6141; SC70-5; MFG Part Num FMS6141S5X
U5: SN74LVC1G04; SC70-5
U6: 74LVC1G3157; SC70-6

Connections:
/MCU/+3.3V: C17.1, C18.1, C19.1, C72.1, L2.2, R6.1, U3.8 (VDD), U6.5 (V+); also elsewhere on the board
/MCU/ADC1: R13.2, U3.3 (+); also elsewhere on the board
/MCU/CSYNC: R15.1, U3.7; also elsewhere on the board
/MCU/ISYNC: Q1.1 (B); also elsewhere on the board
/MCU/MASK: U6.6 (A0); also elsewhere on the board
/can/+5V: C15.1, C16.1, U4.5 (V+); also elsewhere on the board
/video/LEVEL: U5.2; also elsewhere on the board
/video/camera/VIDEO_IN: C12.2, R9.1; also elsewhere on the board
/video/video_circuit/3V3_OSD: C14.3 (IO2), C76.1, R17.1, U5.5 (VCC)
/video/video_circuit/3V3_OSD_FILT: C14.1 (IO1), L2.1
/video/video_circuit/BW_RAW_OUT: R16.2, U5.4
/video/video_circuit/CSYNC_FLT_POS_REF: R6.2, R7.1, R15.2, U3.5 (+)
/video/video_circuit/CSYNC_FLT_VIN: C13.1, R12.1, U3.6 (-)
/video/video_circuit/CSYNC_VREF: R7.2, R8.1, U3.2 (-)
/video/video_circuit/ISYNC_Q_COL: Q1.3 (C), R19.2
/video/video_circuit/OSD_BW_OUT: R16.1, R17.2, R18.1, U6.3 (NC)
/video/video_circuit/OSD_VIDEO_OUT: U6.4 (COM); also elsewhere on the board
/video/video_circuit/RAW_CSYNC_OUT: R12.2, U3.1
/video/video_circuit/VIDEO_IN_BUF: R13.1, R14.2, U4.4 (VOUT)
/video/video_circuit/VIDEO_IN_CLAMP: C12.1, U4.3 (VIN)
/video/video_circuit/VIDEO_IN_OSD: R14.1, R19.1, U6.1 (NO)
GND: C13.2, C14.2 (GND), C15.2, C16.2, C17.2, C18.2, C19.2, C72.2, C76.2, Q1.2 (E), R8.2, R9.2, R18.2, U3.4 (VSS), U4.1 (V-), U4.2 (V-), U5.3 (GND), U6.2 (GND); also elsewhere on the board

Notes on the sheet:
EB res 4K7 B res 4K7
0.6V
hyst +-0.33 V
LP filter to remove 4.43361875 MHz color subcarrier
Csync circuit
A0=1
A0=0

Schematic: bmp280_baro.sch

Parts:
C25: 1uF; SMD_0603
C26: NFM18PC104R1C3; SMD_0603-3T_LC_FILT_RND
R28: 10K; SMD_0603
U7: BMP280

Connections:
/MCU/+3.3V: C25.1, C26.1 (IO1), U7.2 (CSB), U7.6 (VDDIO); also elsewhere on the board
/i2c/bmp280_baro/I2C_SCL: U7.4 (SCL/SCK); also elsewhere on the board
/i2c/bmp280_baro/I2C_SDA: U7.3 (SDA/SDI); also elsewhere on the board
GND: C25.2, C26.2 (GND), R28.2, U7.1 (GND), U7.7 (GND); also elsewhere on the board
unnamed: C26.3 (IO2), U7.8 (VDD)
unnamed: R28.1, U7.5 (I2CA/SDO)

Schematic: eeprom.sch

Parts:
C27: 0.1uF; SMD_0603
U8: M24M01; SOIC8

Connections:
/MCU/+3.3V: C27.1, U8.8 (VCC); also elsewhere on the board
/i2c/bmp280_baro/I2C_SCL: U8.6 (SCL); also elsewhere on the board
/i2c/bmp280_baro/I2C_SDA: U8.5 (SDA); also elsewhere on the board
GND: C27.2, U8.1 (A0), U8.2 (A1), U8.3 (A2), U8.4 (GND), U8.7 (WP); also elsewhere on the board

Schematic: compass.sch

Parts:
C28: 0.1uF; SMD_0603
C29: NFM18PC104R1C3; SMD_0603-3T_LC_FILT_RND
C30: 1uF; SMD_0603
R29: 10K; SMD_0603
U9: LIS3MDL

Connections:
/MCU/+3.3V: C29.3 (IO2), C30.1, U9.6 (VDD_IO), U9.10 (CS); also elsewhere on the board
/i2c/bmp280_baro/I2C_SCL: U9.1 (SCL/SPC); also elsewhere on the board
/i2c/bmp280_baro/I2C_SDA: U9.11 (SDA/SDI/SDO); also elsewhere on the board
/i2c/compass/VDD_COMPASS: C29.1 (IO1), U9.5 (VDD)
GND: C28.2, C29.2 (GND), C30.2, R29.1, U9.2 (RES), U9.3 (GND), U9.12 (RES); also elsewhere on the board
unnamed: C28.1, U9.4 (C1)
unnamed: R29.2, U9.9 (SDO/SA1)

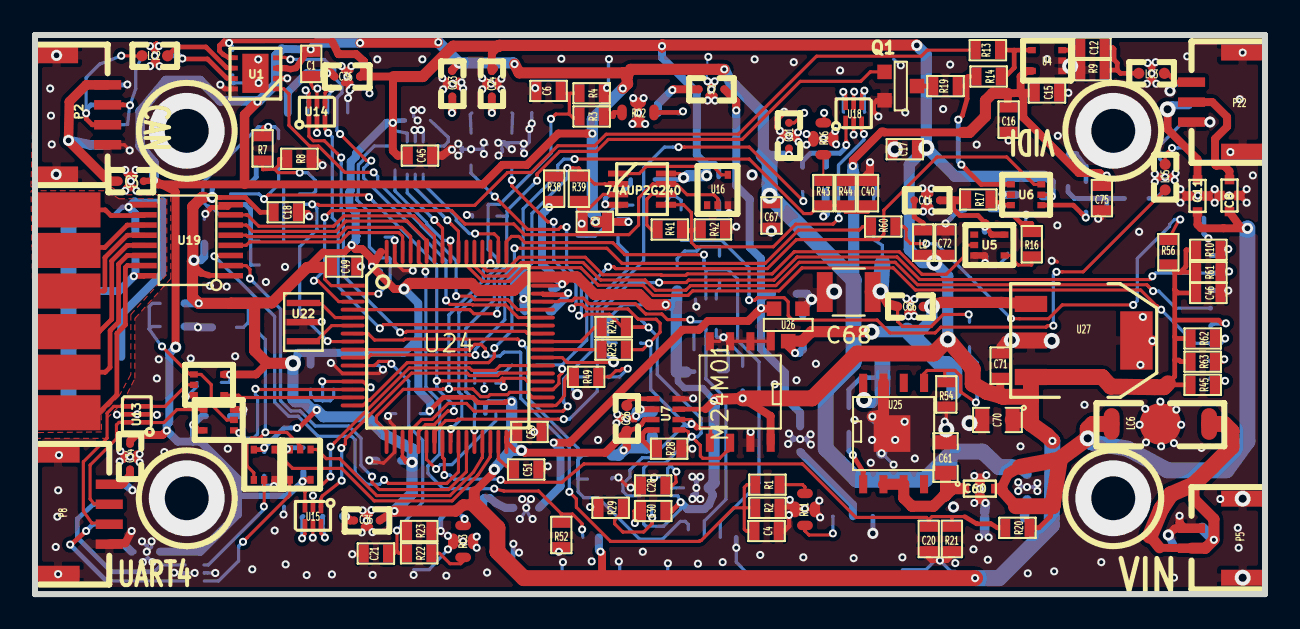
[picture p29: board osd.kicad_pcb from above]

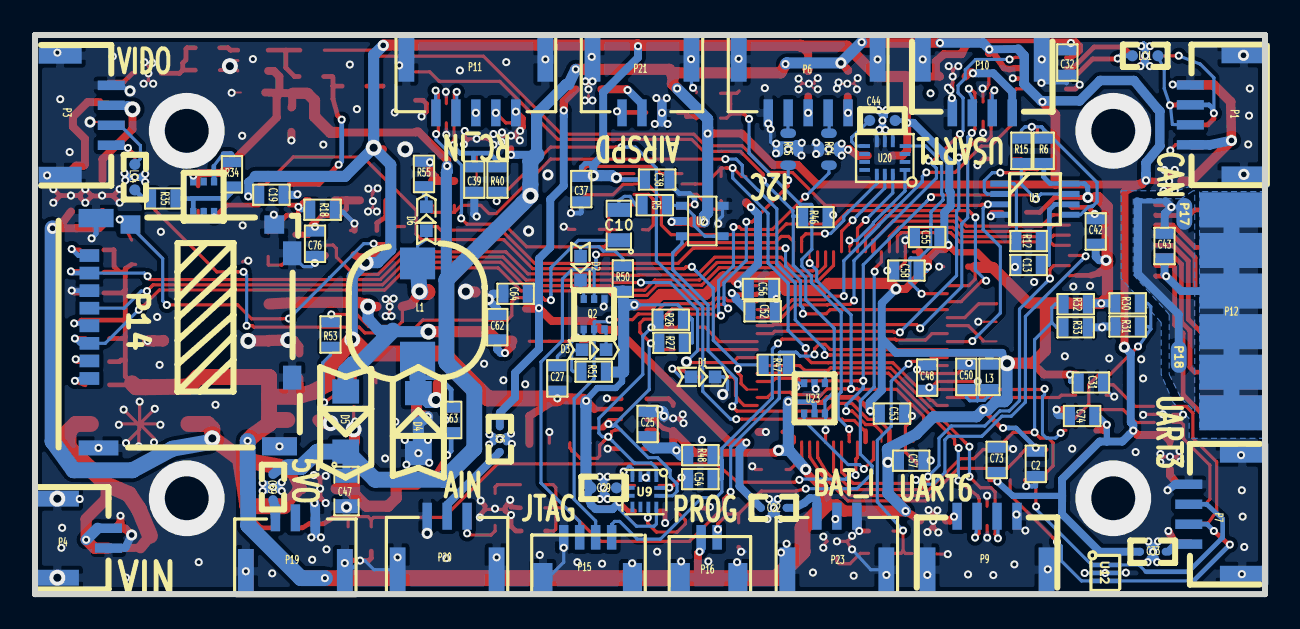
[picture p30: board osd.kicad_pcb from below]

Board: 4 copper layers, 77.0 x 35.0 mm, 207 parts (94 on the bottom side), 164 nets.

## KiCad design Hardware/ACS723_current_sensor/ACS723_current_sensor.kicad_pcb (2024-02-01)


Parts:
C1: C; C_0603
J1, J2, J3, J4: PAD; Pin_Header_Straight_1x01_Pitch2.54mm
J5: JST-GH-3; JST_GH3_horz
R1: R; R_0603
U1: ACS723; SOIC-8_3.9x4.9mm_Pitch1.27mm

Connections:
/+5V: C1.1, J5.2, U1.6 (BW_SEL), U1.8 (VCC)
/BATT_IN: J4.1, U1.1 (IP+), U1.2 (IP+)
/ESC_BATT_GND: J1.1, J3.1
/ESC_OUT: J2.1, U1.3 (IP-), U1.4 (IP-)
/GND: C1.2, J5.3, U1.5 (GND)
/IOUT: J5.1, R1.1
unnamed: R1.2, U1.7 (VIOUT)

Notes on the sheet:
BATT
ESC



Board: 2 copper layers, 8.6 x 11.8 mm, 8 parts (2 on the bottom side), 7 nets.

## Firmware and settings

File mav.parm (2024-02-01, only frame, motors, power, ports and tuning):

BATT2_AMP_OFFSET 0.000000
BATT2_AMP_PERVOL 17.000000
BATT2_CAPACITY   3300.000000
BATT2_CURR_PIN   12.000000
BATT2_MONITOR    0.000000
BATT2_VOLT_MULT  10.100000
BATT2_VOLT_PIN   13.000000
BATT_AMP_OFFSET  0.000000
BATT_AMP_PERVOLT 17.000000
BATT_CAPACITY    3300.000000
BATT_CURR_PIN    12.000000
BATT_MONITOR     0.000000
BATT_VOLT_MULT   10.100000
BATT_VOLT_PIN    13.000000
FLTMODE1         11.000000
FLTMODE2         11.000000
FLTMODE3         5.000000
FLTMODE4         5.000000
FLTMODE5         0.000000
FLTMODE6         0.000000
FLTMODE_CH       8.000000
INS_GYRO_FILTER  20.000000
SERIAL0_BAUD     115.000000
SERIAL1_BAUD     57.000000
SERIAL1_PROTOCOL 1.000000
SERIAL2_BAUD     57.000000
SERIAL2_PROTOCOL 1.000000
SERIAL3_BAUD     38.000000
SERIAL3_PROTOCOL 5.000000
SERIAL4_BAUD     38.000000
SERIAL4_PROTOCOL 5.000000

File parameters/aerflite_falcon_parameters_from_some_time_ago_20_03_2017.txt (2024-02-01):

show

#This is parmeters before of Version before loading 1st mixer version to falcon






FORMAT_VERSION: 13
SYSID_SW_TYPE: 0
SYSID_THISMAV: 1
SYSID_MYGCS: 255
CLI_ENABLED: 1
SERIAL0_BAUD: 115
SERIAL1_PROTOCOL: 1
SERIAL1_BAUD: 57
SERIAL2_PROTOCOL: 1
SERIAL2_BAUD: 57
SERIAL3_PROTOCOL: 5
SERIAL3_BAUD: 38
SERIAL4_PROTOCOL: 5
SERIAL4_BAUD: 38
AUTOTUNE_LEVEL: 6
TELEM_DELAY: 0
GCS_PID_MASK: 0
KFF_RDDRMIX: 0.500000
KFF_THR2PTCH: 0.000000
STAB_PITCH_DOWN: 2.000000
GLIDE_SLOPE_MIN: 15
GLIDE_SLOPE_THR: 5.000000
STICK_MIXING: 1
AUTO_FBW_STEER: 0
TKOFF_THR_MINSPD: 0.000000
TKOFF_THR_MINACC: 0.000000
TKOFF_THR_DELAY: 2
TKOFF_TDRAG_ELEV: 0
TKOFF_TDRAG_SPD1: 0.000000
TKOFF_ROTATE_SPD: 0.000000
TKOFF_THR_SLEW: 0
TKOFF_FLAP_PCNT: 0
FBWA_TDRAG_CHAN: 0
LEVEL_ROLL_LIMIT: 5
LAND_PITCH_CD: 0
LAND_FLARE_ALT: 3.000000
LAND_FLARE_SEC: 2.000000
LAND_DISARMDELAY: 20
LAND_ABORT_THR: 0
NAV_CONTROLLER: 1
ALT_MIX: 1.000000
ALT_CTRL_ALG: 0
ALT_OFFSET: 0
WP_RADIUS: 90
WP_MAX_RADIUS: 0
WP_LOITER_RAD: 60
FENCE_ACTION: 0
FENCE_TOTAL: 0
FENCE_CHANNEL: 0
FENCE_MINALT: 0
FENCE_MAXALT: 0
FENCE_RETALT: 0
FENCE_AUTOENABLE: 0
FENCE_RET_RALLY: 0
STALL_PREVENTION: 1
ARSPD_FBW_MIN: 9
ARSPD_FBW_MAX: 22
FBWB_ELEV_REV: 0
FBWB_CLIMB_RATE: 2
THR_MIN: 0
THR_MAX: 75
TKOFF_THR_MAX: 0
THR_SLEWRATE: 100
FLAP_SLEWRATE: 75
THR_SUPP_MAN: 0
THR_PASS_STAB: 0
THR_FAILSAFE: 1
THR_FS_VALUE: 999
TRIM_THROTTLE: 45
THROTTLE_NUDGE: 1
FS_SHORT_ACTN: 0
FS_SHORT_TIMEOUT: 1.500000
FS_LONG_ACTN: 0
FS_LONG_TIMEOUT: 5.000000
FS_BATT_VOLTAGE: 0.000000
FS_BATT_MAH: 0.000000
FS_GCS_ENABL: 0
FLTMODE_CH: 8
FLTMODE1: 0
FLTMODE2: 0
FLTMODE3: 5
FLTMODE4: 5
FLTMODE5: 11
FLTMODE6: 11
INITIAL_MODE: 0
LIM_ROLL_CD: 4500
LIM_PITCH_MAX: 2000
LIM_PITCH_MIN: -2500
ACRO_ROLL_RATE: 180
ACRO_PITCH_RATE: 180
ACRO_LOCKING: 0
GROUND_STEER_ALT: 0.000000
GROUND_STEER_DPS: 90
TRIM_AUTO: 0
ELEVON_MIXING: 0
ELEVON_REVERSE: 0
ELEVON_CH1_REV: 0
ELEVON_CH2_REV: 0
VTAIL_OUTPUT: 0
ELEVON_OUTPUT: 2
MIXING_GAIN: 0.500000
RUDDER_ONLY: 0
SYS_NUM_RESETS: 155
LOG_BITMASK: 65535
RST_SWITCH_CH: 0
RST_MISSION_CH: 0
TRIM_ARSPD_CM: 1200
SCALING_SPEED: 15.00000
MIN_GNDSPD_CM: 0
TRIM_PITCH_CD: 0
ALT_HOLD_RTL: 10000
ALT_HOLD_FBWCM: 0
MAG_ENABLE: 1
FLAP_IN_CHANNEL: 0
FLAPERON_OUTPUT: 0
FLAP_1_PERCNT: 0
FLAP_1_SPEED: 0
FLAP_2_PERCNT: 0
FLAP_2_SPEED: 0
LAND_FLAP_PERCNT: 0
INVERTEDFLT_CH: 0
HIL_MODE: 0
HIL_SERVOS: 0
HIL_ERR_LIMIT: 5.000000
RTL_AUTOLAND: 0
TRIM_RC_AT_START: 0
CRASH_DETECT: 0
GND_ABS_PRESS: 102484.8
GND_TEMP: 20.02600
GND_ALT_OFFSET: 0.000000
GND_PRIMARY: 0
GPS_TYPE: 1
GPS_TYPE2: 0
GPS_NAVFILTER: 8
GPS_AUTO_SWITCH: 1
GPS_MIN_DGPS: 100
GPS_SBAS_MODE: 2
GPS_MIN_ELEV: -100
GPS_INJECT_TO: 127
GPS_SBP_LOGMASK: -256
GPS_RAW_DATA: 0
GPS_GNSS_MODE: 0
GPS_SAVE_CFG: 0
ARMING_REQUIRE: 0
ARMING_CHECK: 0
ARMING_RUDDER: 0
RELAY_PIN: -1
RELAY_PIN2: -1
RELAY_PIN3: -1
RELAY_PIN4: -1
RELAY_DEFAULT: 0
CHUTE_ENABLED: 0
CHUTE_TYPE: 0
CHUTE_SERVO_ON: 1300
CHUTE_SERVO_OFF: 1100
CHUTE_ALT_MIN: 10
CHUTE_CHAN: 0
RNGFND_LANDING: 0
ADSB_ENABLE: 0
ADSB_BEHAVIOR: 0
RC1_MIN: 900
RC1_TRIM: 1503
RC1_MAX: 2100
RC1_REV: 1
RC1_DZ: 30
RC2_MIN: 900
RC2_TRIM: 1502
RC2_MAX: 2100
RC2_REV: 1
RC2_DZ: 30
RC3_MIN: 1050
RC3_TRIM: 1050
RC3_MAX: 2100
RC3_REV: 1
RC3_DZ: 30
RC4_MIN: 1100
RC4_TRIM: 1504
RC4_MAX: 1900
RC4_REV: 1
RC4_DZ: 30
RC5_MIN: 1100
RC5_TRIM: 1500
RC5_MAX: 1900
RC5_REV: 1
RC5_DZ: 0
RC5_FUNCTION: 0
RC6_MIN: 1100
RC6_TRIM: 1500
RC6_MAX: 1900
RC6_REV: 1
RC6_DZ: 0
RC6_FUNCTION: 0
RC7_MIN: 1100
RC7_TRIM: 1500
RC7_MAX: 1900
RC7_REV: 1
RC7_DZ: 0
RC7_FUNCTION: 0
RC8_MIN: 1100
RC8_TRIM: 1500
RC8_MAX: 1900
RC8_REV: 1
RC8_DZ: 0
RC8_FUNCTION: 0
RLL2SRV_TCONST: 0.500000
RLL2SRV_P: 1.000000
RLL2SRV_D: 0.020000
RLL2SRV_I: 0.040000
RLL2SRV_RMAX: 0
RLL2SRV_IMAX: 3000
RLL2SRV_FF: 0.000000
PTCH2SRV_TCONST: 0.500000
PTCH2SRV_P: 1.000000
PTCH2SRV_D: 0.020000
PTCH2SRV_I: 0.040000
PTCH2SRV_RMAX_UP: 0
PTCH2SRV_RMAX_DN: 0
PTCH2SRV_RLL: 1.000000
PTCH2SRV_IMAX: 3000
PTCH2SRV_FF: 0.000000
YAW2SRV_SLIP: 0.000000
YAW2SRV_INT: 0.000000
YAW2SRV_DAMP: 0.000000
YAW2SRV_RLL: 1.000000
YAW2SRV_IMAX: 1500
STEER2SRV_TCONST: 0.750000
STEER2SRV_P: 1.800000
STEER2SRV_I: 0.200000
STEER2SRV_D: 0.005000
STEER2SRV_IMAX: 1500
STEER2SRV_MINSPD: 1.000000
STEER2SRV_FF: 0.000000
COMPASS_OFS_X: 332.0000
COMPASS_OFS_Y: 332.0000
COMPASS_OFS_Z: -620.0000
COMPASS_DEC: 0.000000
COMPASS_LEARN: 0
COMPASS_USE: 1
COMPASS_AUTODEC: 0
COMPASS_MOTCT: 0
COMPASS_MOT_X: 0.000000
COMPASS_MOT_Y: 0.000000
COMPASS_MOT_Z: 0.000000
COMPASS_ORIENT: 4
COMPASS_EXTERNAL: 1
COMPASS_OFS2_X: 0.000000
COMPASS_OFS2_Y: 0.000000
COMPASS_OFS2_Z: 0.000000
COMPASS_MOT2_X: 0.000000
COMPASS_MOT2_Y: 0.000000
COMPASS_MOT2_Z: 0.000000
COMPASS_PRIMARY: 0
COMPASS_OFS3_X: 0.000000
COMPASS_OFS3_Y: 0.000000
COMPASS_OFS3_Z: 0.000000
COMPASS_MOT3_X: 0.000000
COMPASS_MOT3_Y: 0.000000
COMPASS_MOT3_Z: 0.000000
COMPASS_DEV_ID: 9
COMPASS_DEV_ID2: 0
COMPASS_DEV_ID3: 0
COMPASS_USE2: 0
COMPASS_ORIENT2: 0
COMPASS_EXTERN2: 0
COMPASS_USE3: 0
COMPASS_ORIENT3: 0
COMPASS_EXTERN3: 0
COMPASS_DIA_X: 1.000000
COMPASS_DIA_Y: 1.000000
COMPASS_DIA_Z: 1.000000
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

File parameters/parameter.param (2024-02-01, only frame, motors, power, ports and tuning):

ATC_ANGLE_BOOST,1
ATC_RATE_FF_ENAB,1
BATT2_AMP_OFFSET,0.00000000
BATT2_AMP_PERVOL,17.00000000
BATT2_CAPACITY,3300
BATT2_CURR_PIN,3
BATT2_MONITOR,0
BATT2_VOLT_MULT,10.10000038
BATT2_VOLT_PIN,2
BATT_AMP_OFFSET,0.00000000
BATT_AMP_PERVOLT,17.00000000
BATT_CAPACITY,3300
BATT_CURR_PIN,3
BATT_MONITOR,0
BATT_VOLT_MULT,10.10000038
BATT_VOLT_PIN,2
FLTMODE1,0
FLTMODE2,0
FLTMODE3,3
FLTMODE4,3
FLTMODE5,6
FLTMODE6,6
FRAME,1
INS_GYRO_FILTER,20
MOT_CURR_MAX,0.00000000
MOT_SPIN_ARMED,70
MOT_THR_MIX_MAX,0.50000000
MOT_THR_MIX_MIN,0.10000000
MOT_THST_BAT_MAX,0.00000000
MOT_THST_BAT_MIN,0.00000000
MOT_THST_EXPO,0.64999998
MOT_THST_MAX,0.94999999
MOT_YAW_HEADROOM,200
SERIAL0_BAUD,115
SERIAL1_BAUD,57
SERIAL1_PROTOCOL,1
SERIAL2_BAUD,57
SERIAL2_PROTOCOL,1
SERIAL3_BAUD,38
SERIAL3_PROTOCOL,5
SERIAL4_BAUD,38
SERIAL4_PROTOCOL,5

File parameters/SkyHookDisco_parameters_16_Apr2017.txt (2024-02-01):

Discovery
Change 
FBWA_MIN = 12 m/s
AHRS_ORIENTATION = 6  # YAW_270
COMPASS_ORIENT   = 6 # YAW_270
